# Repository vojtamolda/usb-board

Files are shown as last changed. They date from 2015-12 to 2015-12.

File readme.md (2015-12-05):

# USB Measuring Board & USB Attenuator

Wouldn't be cool to drive any experiment directly from your computer? Without the need to get up from your chair and touch things? Well, now your computer can directly flip switches, measure voltages, send signals and talk to other devices using the *USB Measuring Board* or *USB Attenuator*!

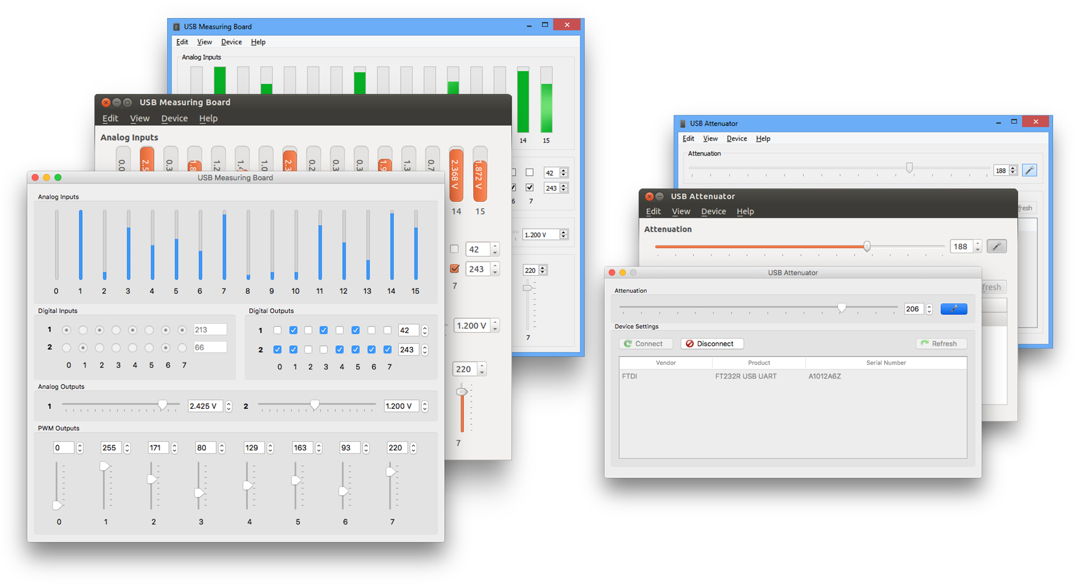
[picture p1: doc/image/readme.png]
board_diagram USB Measuring Board & USB Attenuator

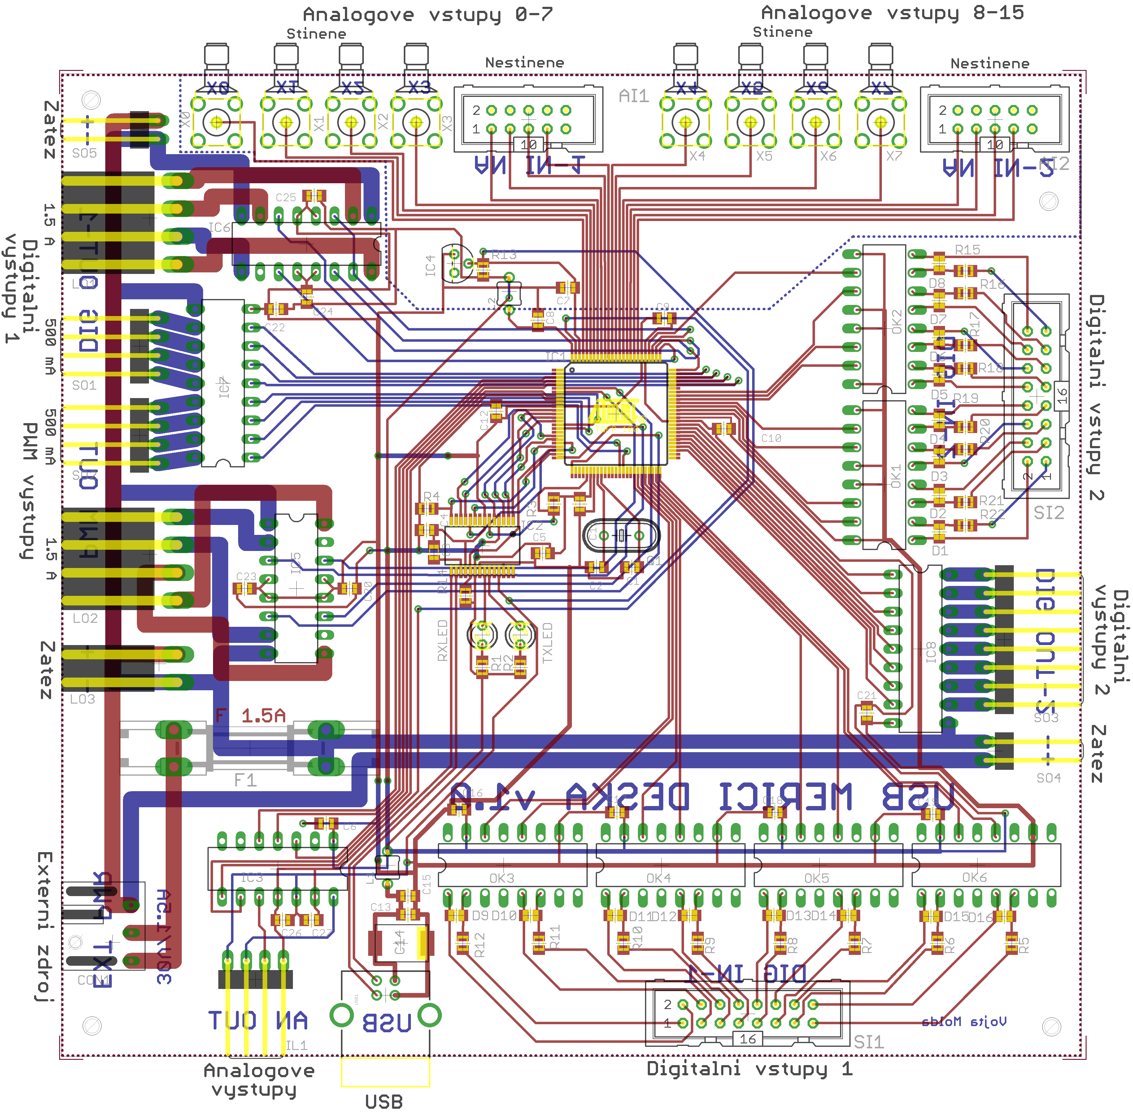
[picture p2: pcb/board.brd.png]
board_pcb Printed Circuit Board


If your applications is simple and requires just a few inputs and outputs then [*USB Attenuator*](/doc/attenuator.md) is the right solution. [*USB Measuring Board*](/doc/board.md) is more versatil and can handle control of more complex experiments. See [board.md](/doc/board.md) and [attenuator.md](/doc/attenuator.md) readme files for more details.

Both projects were originally inspired by the needs of the [Department of Low-Temperature Physics, Charles University, Prague](http://kfnt.mff.cuni.cz), but obviously range of application is much wider. *USB Measuring Board* was developed as part of my [bachelor thesis](/doc/thesis.pdf) written in 2009. If you're interested in how it all works, take a look at the  [prototypes](/prototypes/prototypes.md).

## Compilation
So... How do I build this monster? It's not as complicated as it looks. Build chain uses *QMake* (part of [*Qt framework*](http://qt.io)). Besides *Qt*, you'll need two libraries that provide USB communication - [*libftdi*](http://www.intra2net.com/en/developer/libftdi/index.php) and [*libusb*](http://libusb.info/). Tested platforms are Mac OS X 10.11, Ubuntu Linux 14.04 LTS and Windows 8, but chances are it would run on any platform supported by *Qt* and *libusb*.

Firmware powering the ATmega microprocessor requires it's own version C compiler, linker and standard C libraries called [*avr-toolchain*](http://savannah.nongnu.org/projects/avr-libc/). To upload the firmware no special programmer is needed. Microprocessor programming can be done over the USB cable by [*avrdude*](http://savannah.nongnu.org/projects/avrdude/).

#### Mac OS X
- Download and install latest version of *Qt* 5.x libraries from [here](http://www.qt.io/download/).
- Install *libftdi* library. [Homebrew](http://brew.sh/) installs *libusb* automatically as a dependency.
```bash
   # Get Homebrew OS X package manager here: http://brew.sh/.
   brew install libftdi
```
- Install [*avr-gcc*](https://gcc.gnu.org/wiki/avr-gcc), [*avr-libc*](http://savannah.nongnu.org/projects/avr-libc/)  and [*avrdude*](http://savannah.nongnu.org/projects/avrdude/) required to compile and upload firmware.
```bash
   # Alternatively download and install CrossPack.
   brew install avrdude
   brew tap larsimmisch/avr
   brew install avr-libc
```
- Compile both projects with *QMake* and make.
```bash
   # Alternatively open the .pro file in Qt Creator IDE.
   qmake board.pro
   qmake attenuator.pro
   cd firmware; make;
```
- Remove colliding OS X kernel extension and run the compiled application.
```bash
   # Remove AppleUSBFTDI kernel extension to prevent 'Unable to claim USB device' errors.
   sudo kextunload -bundle-id com.apple.driver.AppleUSBFTDI
```

#### Linux
- Install your distribution's default version of *Qt* 5.x libraries.
```bash
   # DEB-based distributions. (Ubuntu, Debian...)
   apt-get install qt5-default
   # RPM-based distributions. (RedHat, SUSE...)
   yum install qt5-default
```
- Install development version of *libftdi-dev* library. Package manager installs *libusb-dev* automatically as a dependency.
```bash
   # DEB-based distributions.
   apt-get install libftdi-dev
   # RPM-based distributions.
   yum install libftdi-dev
```
- Install [*avr-gcc*](https://gcc.gnu.org/wiki/avr-gcc), [*avr-libc*](http://savannah.nongnu.org/projects/avr-libc/)  and [*avrdude*](http://savannah.nongnu.org/projects/avrdude/) required to compile and upload firmware.
```bash
   # DEB-based distributions.
   apt-get install avrdude avr-gcc avr-libc
   # RPM-based distributions.
   yum install avrdude avr-gcc avr-libc
```
- Compile both projects with *QMake*.
```bash
   # Alternatively open the .pro file in Qt Creator IDE.
   qmake board.pro
   qmake attenuator.pro
   cd firmware; make
```
- Remove conflicting kernel module and run the compiled application.
```bash
   # Unload kernel module to prevent 'Unable to claim USB device' errors.
   sudo rmmod ftdi_sio
```

#### Windows
- Download and install latest version of *Qt* 5.x libraries from [here](http://www.qt.io/download/).
- Download and compile libraries required for USB communication.
  - Source code and documentation for *libusb* is available [here](http://github.com/libusb/libusb/)
  - Source code and documentation for *libftdi* is available [here](http://www.intra2net.com/en/developer/libftdi/repository.php).
  - Copy freshly compiled static libraries and headers (*ftdi.h*, *usb.h*, *libftdi.lib* and *libusb.lib*) into *lib/win32/*.
- Download and install [*WinAVR*](http://winavr.sourceforge.net/) required to compile and upload firmware.
- Compile both projects with *QMake*.
```bat
   :: Alternatively open the .pro file in Qt Creator IDE.
   qmake.exe board.pro
   qmake.exe attenuator.pro
   cd firmware; make.exe
```

## Schematics and PCB Layouts
Circuit schematics (.sch) and PCB layouts (.brd) files are designed with [Eagle CAD](http://www.cadsoftusa.com/). Free version for non-commercial use version can be downloaded [here](http://www.cadsoftusa.com/download-eagle/).

## License
This work is licensed under the [GNU GPL 3.0 License](http://www.gnu.org/licenses/gpl-3.0.html) © 2009.

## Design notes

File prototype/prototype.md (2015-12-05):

# Breadboard Prototypes

## What's this?
Following page contains descriptions of three simple prototype applications that served as proof of concept. These files are here to show and document the development path (i.e. dead ends) towards [USB Attenuator](/doc/attenuator.md) and [USB Measuring Board](/doc/board.md).

## Discover
This application tests basic functionality of the *libftdi* library. It detects and prints out a detailed list of all available FTDI chips. Any (FT232/245/2232 etc..) known model is detected and listed.

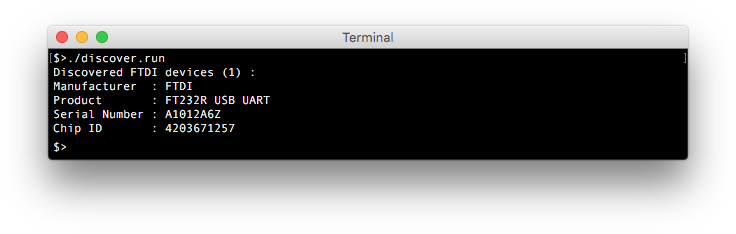
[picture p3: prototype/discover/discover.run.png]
bitbang_application Discover Prototype Application


If the application ends up with an error or doesn't detect any device, typically there's a collision between *libftdi* and OS kernel driver. Please, see the *Compilation* section of the [readme file](/readme.md) for more details on how to unload the colliding kernel driver for each OS.

## Bitbang
This prototype tests the bitbang mode. Bitbang mode allows direct access to pins of FT232R IC. Pins can be setup as either input or output. Based on the supplied argument, the application launches in two different modes -
input mode `i`, that reads state of connected switches or output mode `o`, which can for example blink LEDs.
 
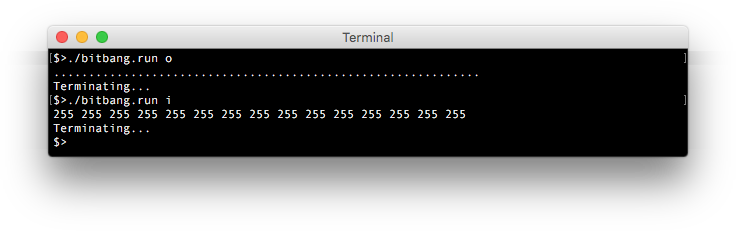
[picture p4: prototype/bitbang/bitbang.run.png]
bitbang_application Bitbang Prototype Application


Example connection schematics that can be used for input and output mode are shown on the following picture. In case of the output mode, every GPIO is connected to a 330Ω resistor and a LED. Input mode uses the same resistors as pull-downs and switches connect the GPIO lines to +5V.

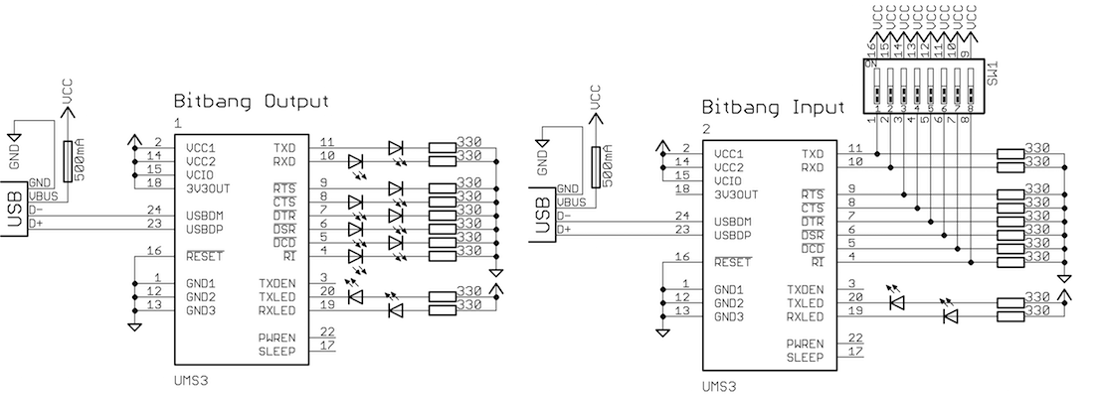
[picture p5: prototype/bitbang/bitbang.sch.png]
bitbang_schematics Bitbang Prototype Schematics


PS: I know 330 Ω pull-down resistors are a silly idea, since it wastes a ton of power when the switches are on, but I'm too lazy to change the breadboard and nobody cares about prototypes anyway :-)

## ATmega168
This breadboard prototype is a smaller brother of [USB Measuring Board](/doc/board.md). Instead of gigantic ATmega1280 with hundreds of legs, this prototype uses ATmega168 in DIP-28 package. Both microcontrollers use the same RISC instruction set, so the main difference is only the number of GPIO ports.

Key feature of the prototype is the ability to program the microcontroller directly via the USB cable, without the need for any external programmer. This allows for quick development cycles and easy firmware updates once the board is deployed into production.

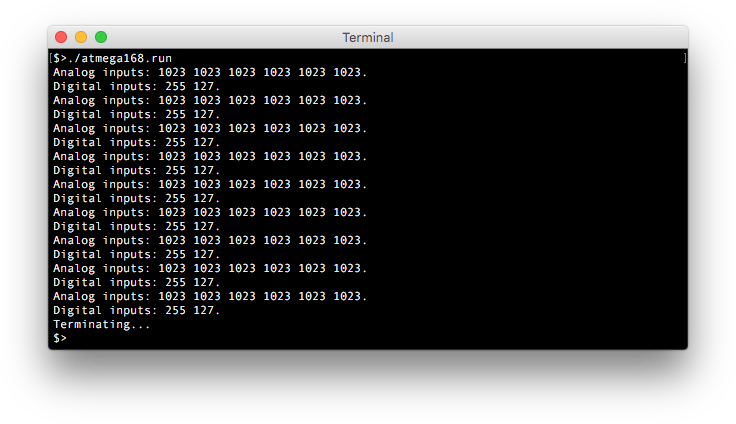
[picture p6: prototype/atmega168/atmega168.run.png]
atmega168_application ATmega168 Prototype Application


Application running on the PC and the firmware running on the ATmega microcontroller talk to each other via USB to serial port converter provided by the FT232R IC sitting on UMS3 module. UMS3 is just a convenient breakout DIP package for FT232R IC and it isn't used in the production models. After receiving data packet from the serial port ATmega168 firmware sets the values of analog outputs via SPI interface and sets the state of the digital output GPIO pins. After that it sends back the values of analog and digital inputs.

Controlling application running on the PC periodically scans and prints out the values of analog (10-bit value) and digital inputs to the terminal. Values of analog and digital outputs transmitted into the microcontroller are hard-coded into the source code.

Following picture shows schematics of the ATmega breadboard and list of used ICs and their function:

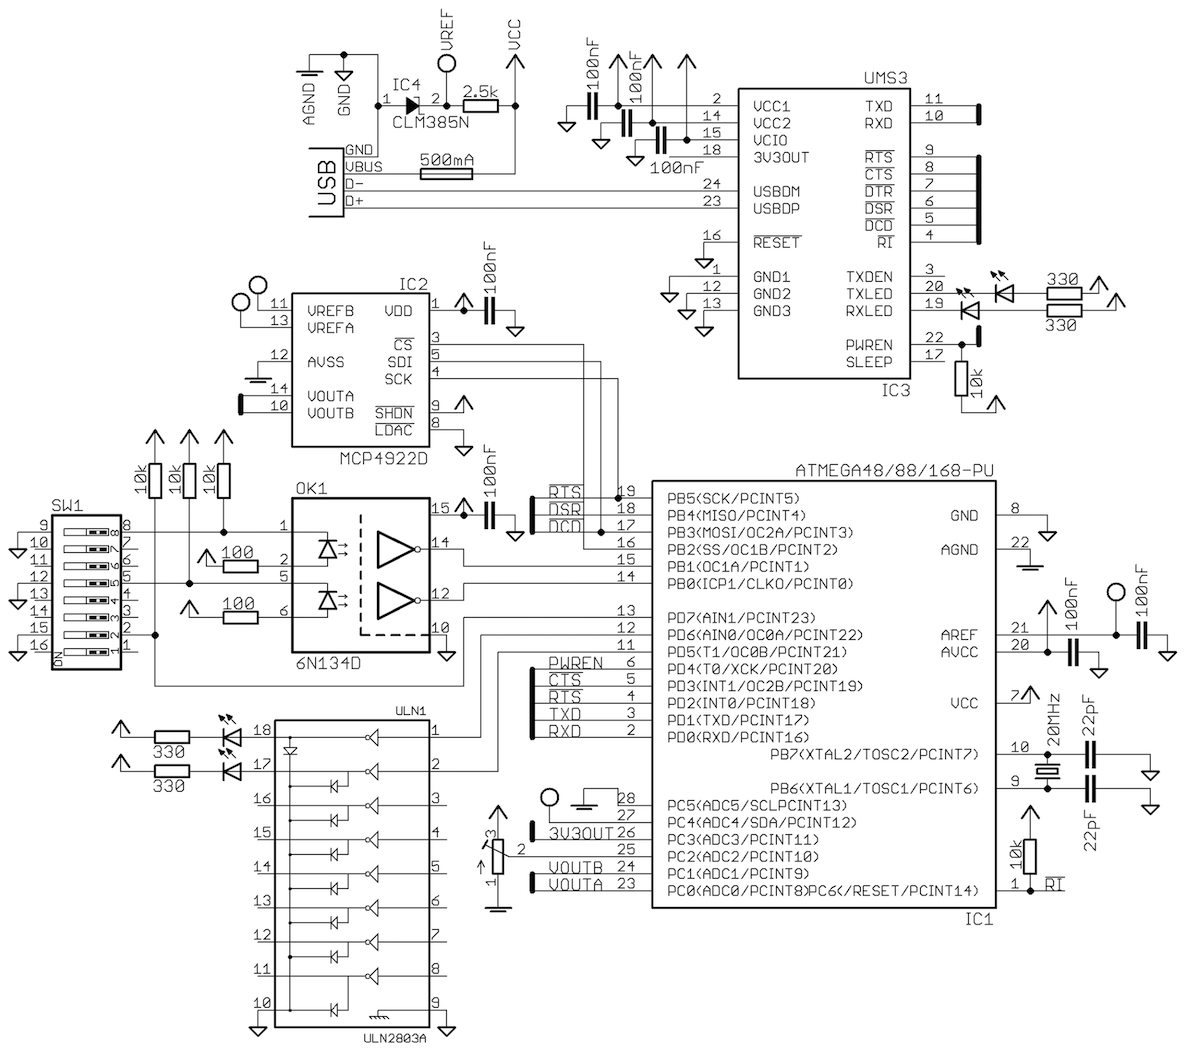
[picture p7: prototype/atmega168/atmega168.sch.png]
atmega168_schematics ATmega168 Prototype Schematics


| IC | Interface | Function
|---|---|---
| ATmega168 | UART | RISC 8-bit microcontroller (running at 20 MHz)
| UMS3 | USB | USB to UART converter (breakout for FT232R)
| MCP4922P  | SPI | Digital to analog converter (12-bit precision)
| ULN2803A  | GPIO | Darlington driver for digital outputs (500mA max. current)
| 6N134D | GPIO | Optocoupler for galvanic separation of digital inputs
| CLM385M | N/A | Voltage 2.5V reference for digital-analog and analog-digital converters

Here's a photograph of the assembled breadboard in it's full beauty :) 

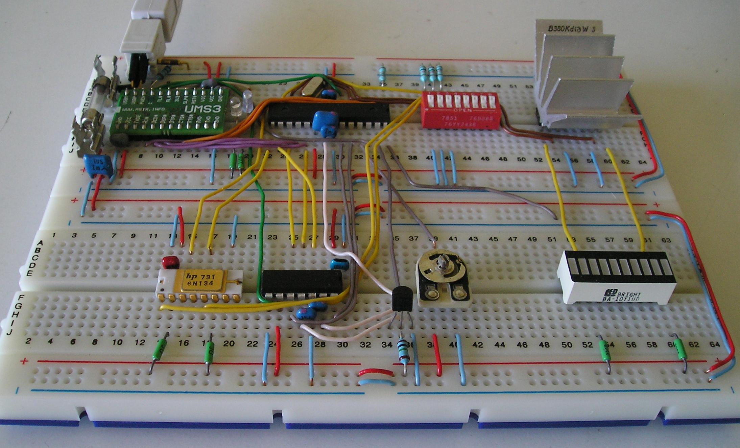
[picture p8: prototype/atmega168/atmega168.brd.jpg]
atmega168_breadboard ATmega168 Prototype Breadboard


For more details, please see *Chapter 5 - Prototype* of the bachelor [thesis](/doc/thesis.pdf) (available only in Czech).

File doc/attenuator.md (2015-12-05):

# USB Attenuator

## How does it work?
Essentially, you stick USB cable into the gadget one side and custom parallel port signals get out on the other side. To make the device work two things are needed - some hardware and an application that can talk to that hardware.

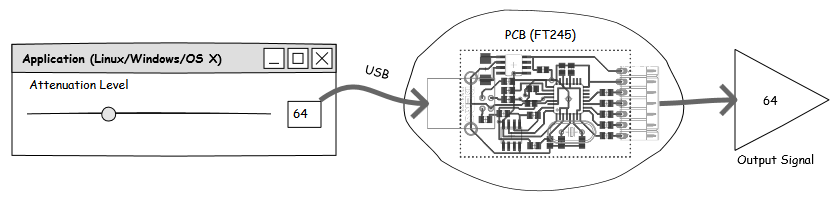
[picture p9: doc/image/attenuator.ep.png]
diagram Diagram


## Application
Under the hood of the *USB Attenuator* application sits the [*Qt* framework](http://qt.io). Hardware communication uses [*libftdi*](http://www.intra2net.com/en/developer/libftdi/index.php) and [*libusb*](http://libusb.info/). These libraries allow the USB communication code to be written only once, since they provide an abstraction layer from the underlying OS specific API.

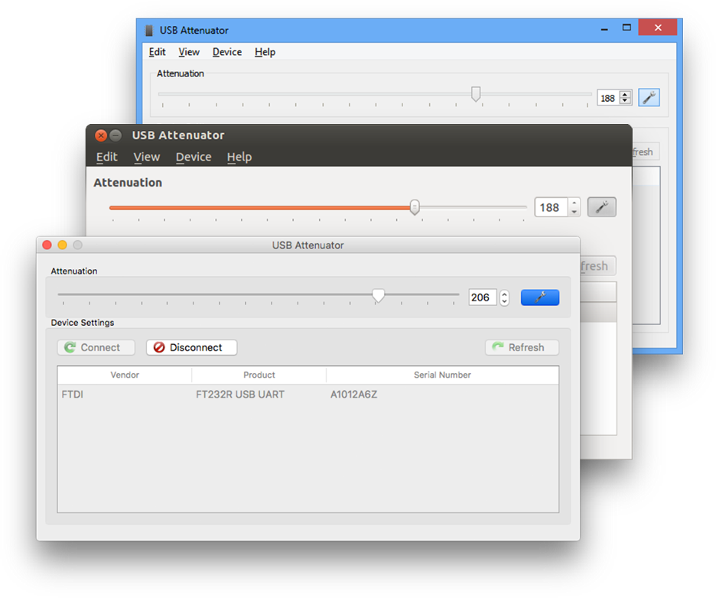
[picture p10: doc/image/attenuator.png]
application Application


For detailed instructions on how to compile the application, please see the [readme.md](readme.md) file. No worries. It's not as complicated as it sounds.

## Electronics
All the magic happens thanks to the built-in bit-bang mode of the FT245 IC. Other parts are there just to help the FT245 do it's job. You can can read tons more details about the IC in the [datasheet](http://www.ftdichip.com/Support/Documents/DataSheets/ICs/DS_FT245R.pdf).

### Schematics
The PCB contains FT245 (*IC1*) chip which is essentially a black-box with USB (2.0 480Mb/s) on one side and parallel port (RS-485) on the other side. The rest of the parts is there just to make the FT245 work. The FT245 chip is a bit sclerotic and tends to forget its name (Vendor and Product IDs). Because of this there's a three-wire serial EEPROM (93C46 - *IC3*) that keeps the configuration data. Old fashioned RS-485 use +/- 5 V levels so the board is equipped with a voltage converter (ICL7660 - *IC2*). The rest is just standard connectors, filtering capacitors, ferrite cores and resistors.

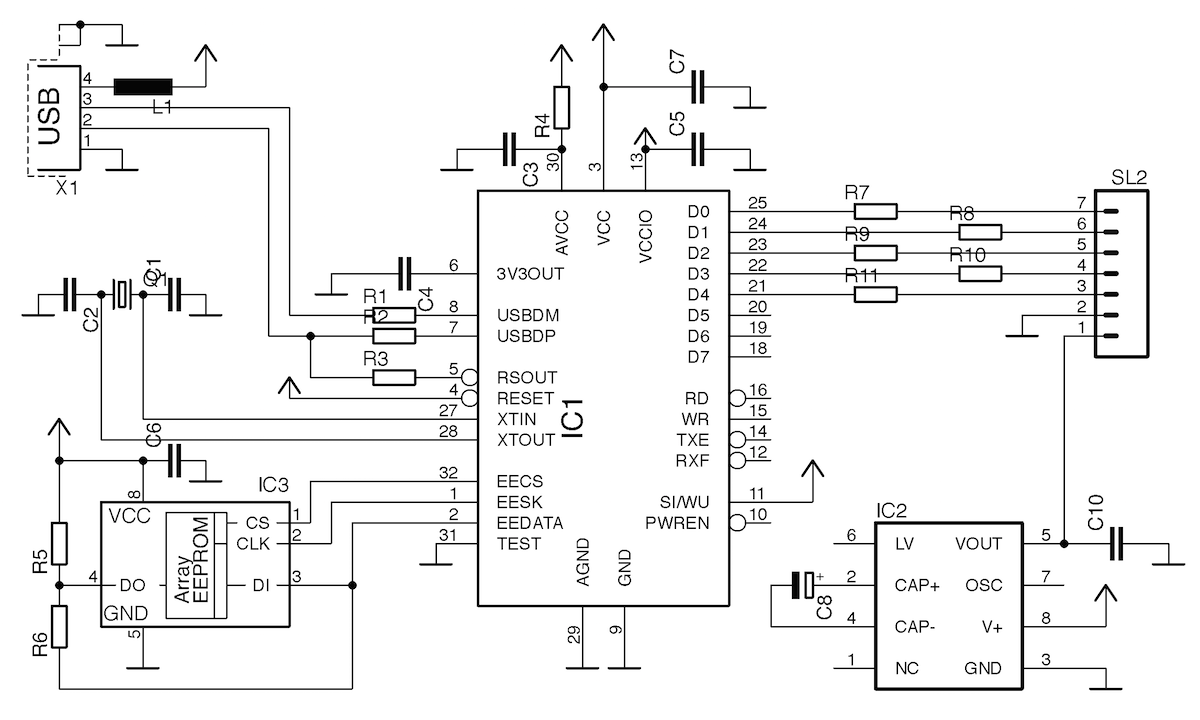
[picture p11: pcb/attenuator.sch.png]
schematics Schematics


### Printed Circuit Board
The PCB is designed as two-sided, but it's possible to use only one sided etching photomask and three jumper wires, which is a good compromise that prevents alignment problems that arise with two sided PCBs. Happy soldering!

| IC | Interface | Function
|---|---|---
| FT245BL (IC1) | USB | USB to parallel port converter
| ICL7660SA (IC2) | N/A | Negative voltage converter (outputs -5V)
| 93-C46ASN (IC3) | SPI | Microwire compatible serial 1kB EEPROM (keeps USB descriptors)

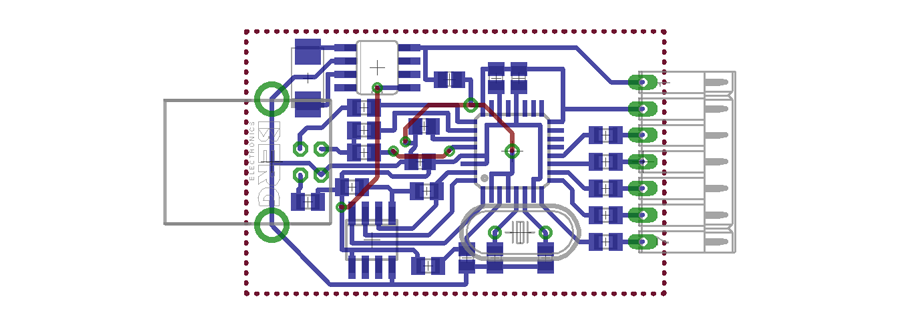
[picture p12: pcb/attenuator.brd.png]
pcb Printed Circuit Board


 - Dimensions 25 x 40 x 12 mm / 1.0 x 1.6 x 0.5 in
 - Operating temperature range: -40 to +70 °C / -40 to +160 °F
 - Weight: 3.8 g / 0.16 oz

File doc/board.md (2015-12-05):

# USB Measuring Board

## How does it work?
Essentially, you stick USB cable into the gadget one side and whole bunch of input and output signals start to blink on the other side. To make the device work two things are needed - some hardware and an application that can talk to that hardware.

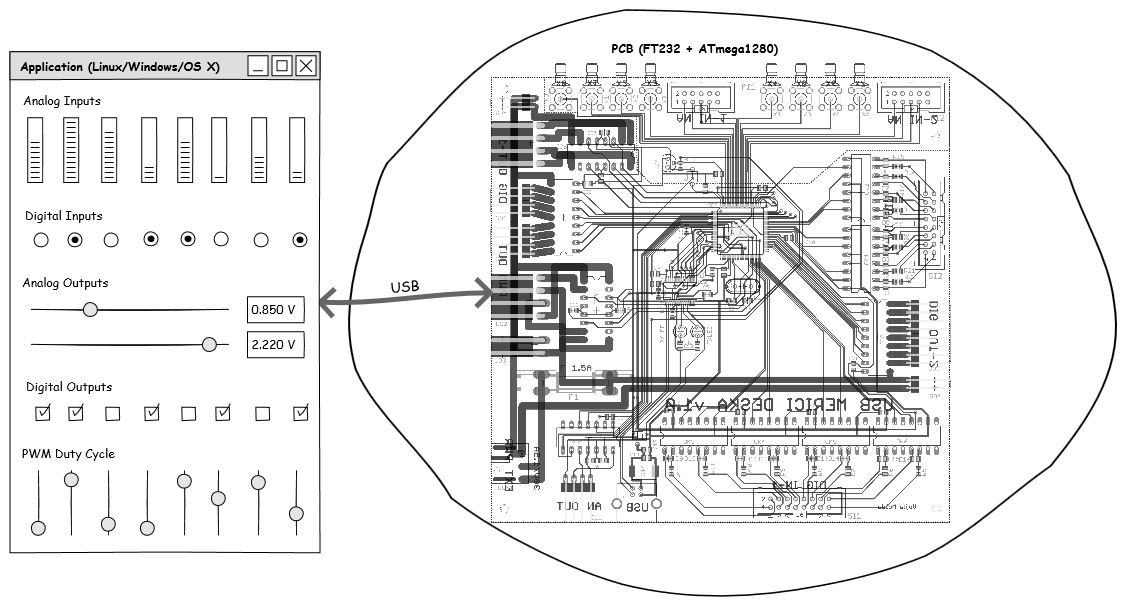
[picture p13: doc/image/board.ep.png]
diagram Diagram


## Application
Under the hood of the *USB Measuring Board* application sits the [*Qt* framework](http://qt.io). Hardware communication uses [*libftdi*](http://www.intra2net.com/en/developer/libftdi/index.php) and [*libusb*](http://libusb.info/). These libraries allow the USB communication code to be written only once, since they provide an abstraction layer from the underlying OS specific API.

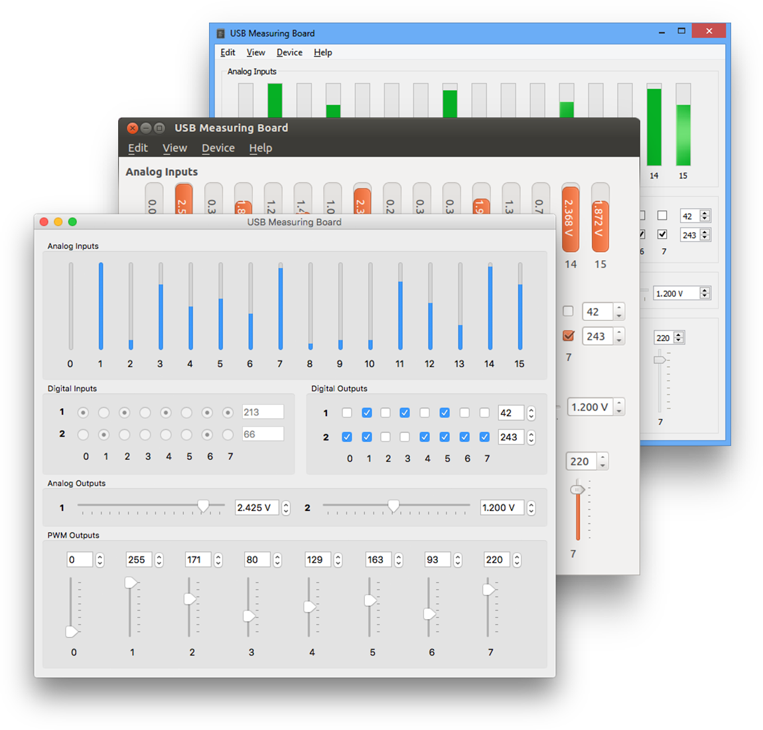
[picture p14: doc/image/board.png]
application Application


For detailed instructions on how to compile the application, please see the [readme.md](readme.md) file. No worries. It's not as complicated as it sounds.

## Firmware
Key feature of the board design is the ability to program the microcontroller directly via the USB cable, without the need for any external programmer. This allows quick development cycles and easy firmware updates once the board is deployed into production. 

Controlling application running on the PC periodically polls the board. The packet going into the device contains fresh values of digital and analog outputs the user has set. Board sends back measured values of digital and analog inputs which are then displayed to the user. 

After receiving a data packet from the serial port firmware running on the ATmega1280 sets the desired value of all outputs and PWMs. Then it sends back the values of analog and digital inputs.

## Electronics
All the magic happens thanks to just two ICs - ATmega 1280 and FT232 IC. ATmega 1280 microcontroller is the brain of the operation and FT232 provides USB communication. Other parts are there just to help these two do their job. You can read tons more details about both ICs in their datasheets [here](http://www.atmel.com/Images/Atmel-2549-8-bit-AVR-Microcontroller-ATmega640-1280-1281-2560-2561_datasheet.pdf) and [here](http://www.ftdichip.com/Support/Documents/DataSheets/ICs/DS_FT245R.pdf).

#### Schematics
Following picture shows schematics of the ATmega breadboard and list of used ICs and their function:

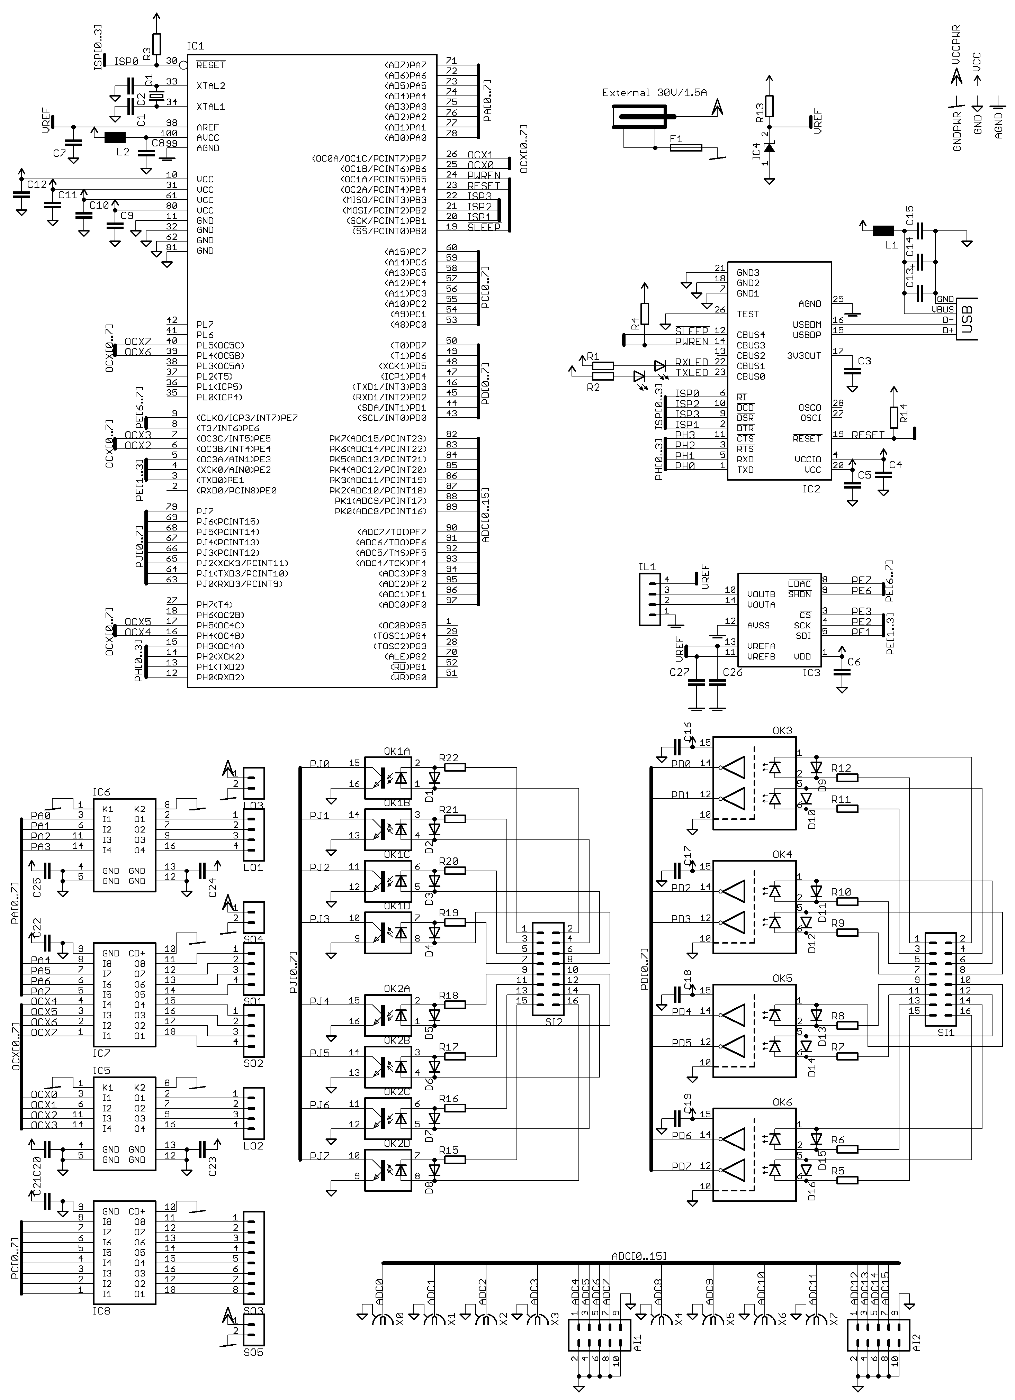
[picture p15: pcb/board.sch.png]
schematics Schematics


The PCB contains FT232 (*IC2*) chip which works as a black-box with USB (2.0 480Mb/s) on one side and serial port (RS-232) on the other side. The logic of the communication is handled in the ATmega1280 (*IC1*) microcontroller. The rest of the parts is there just to support the microcontroller to do its job.

Outputs of ATmega1280 can be loaded only with 20mA current. Because of this limitations all outputs are provided with power amplification. Darlington driver ULN2803A (*IC6,8*) can handle 500mA and ULN2064B outputs are capable of 1.5A. Two analog outputs are provided by MCP4922P (*IC3*) 12-bit analog converter. The MCP4922P and the ATmega microprocessor communicate via SPI bus.

Digital inputs are galvanically separated from the board to reduce the risk of damage. Two kinds of optocouplers are used - PC849 (*OK1-2*) and HCPL2630 (*OK3-6*).

#### Printed Circuit Board
The PCB is designed as two-sided and tolerances are relatively large, so it can be manufactured via traditional laboratory optical etching mask.

| IC | Interface | Function
|---|---|---
| ATmega1280 (IC1) | UART | RISC 8-bit microcontroller (running at 16 MHz)
| FT232R (IC2) | USB | USB to UART converter
| MCP4922P (IC3) | SPI | Digital to analog converter (12-bit precision)
| CLM385M (IC4) | N/A | Voltage 2.5V reference for digital-analog and analog-digital converters
| ULN2803A (IC6,8) | GPIO | Darlington driver for digital outputs (500mA max. current)
| ULN2064B (IC5,7) | GPIO | Darlington driver for digital outputs (1.5A max. current)
| PC849 (OK1-2) | GPIO | Optocoupler for galvanic separation of digital inputs (4 channel)
| HCPL2630 (OK3-6) | GPIO | Optocoupler for galvanic separation of digital inputs (2 channel)

pcb Printed Circuit Board

 - Dimensions 140 x 135 x 20 mm / 5.5 x 5.3 x 0.8 in
 - Operating temperature range: -40 to +70 °C / -40 to +160 °F
 - Weight: 130 g / 4.5 oz

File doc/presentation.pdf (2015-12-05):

# Univerzální USB modul pro sběr dat a řízení fyzikálního experimentu

## Vojta Molda

# Obsah

# - Zadání

# - Zvolená koncepce - Funkce zařízení - Realizace - Software

# - Připomínky a poděkování

# Cíle práce

# Cíle práce

- Navrhněte modul, který bude připojen přes USB rozhraní k libovolnému PC a jehož vstupy a výstupy bude možné modifikovat pro připojení k libovolnému fyzikálnímu experimentu.
- Napište obslužný program v C++ k tomuto modulu pro operační systém Windows XP.
- Vzhledem k univerzálnosti modulu je třeba počítat s minimálně 16 analogovými a digitálními vstupy.
- Výstupy modulu budou rovněž analogové i digitální. Digitální výstupy budou minimálně velikosti 8b. Nejméně část z nich bude schopna výkonového zatížení.

# Zvolená koncepce

# Zvolená koncepce

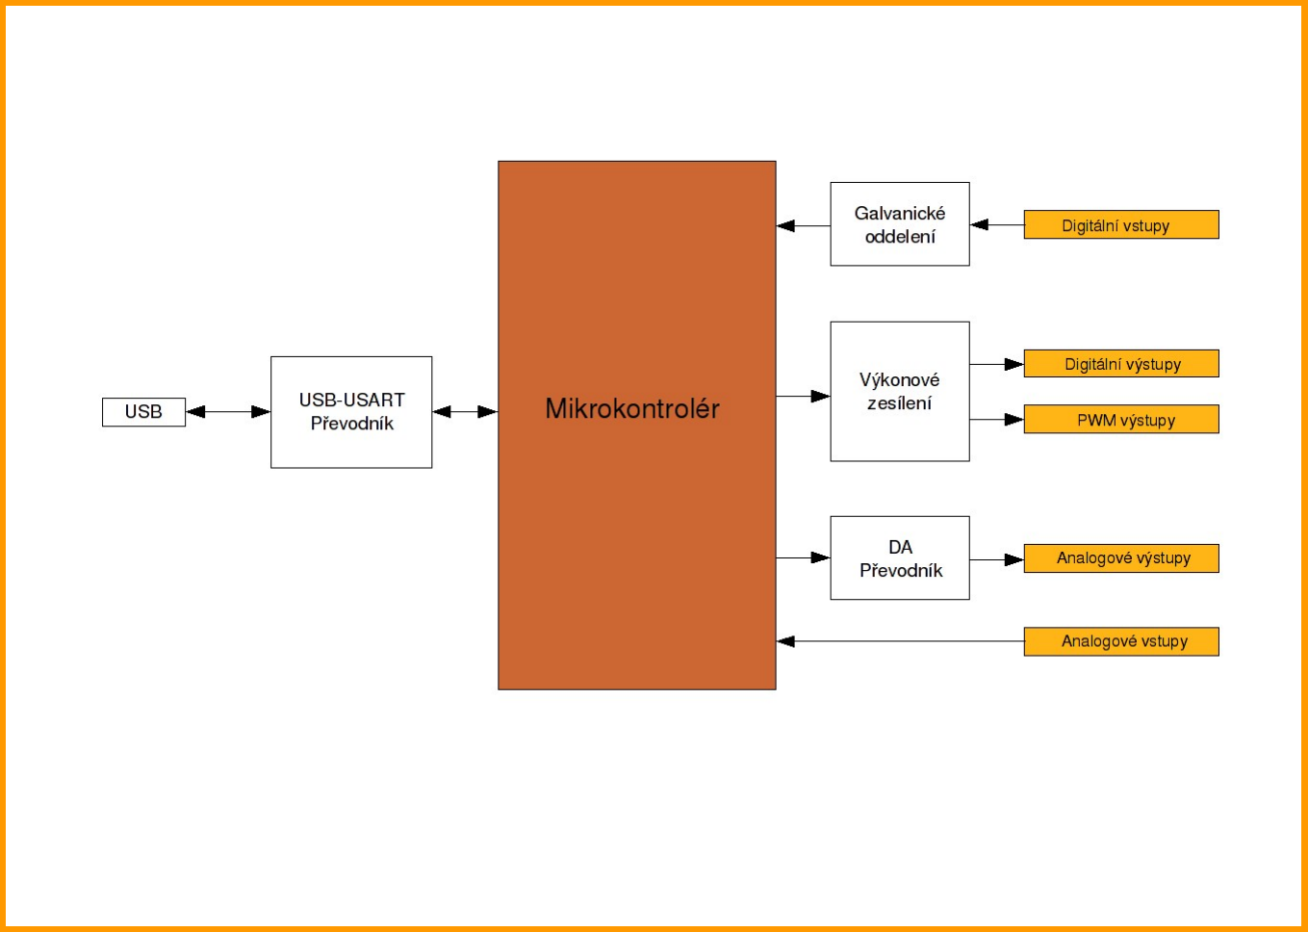
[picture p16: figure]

# Funkce zařízení

# Funkce zařízení

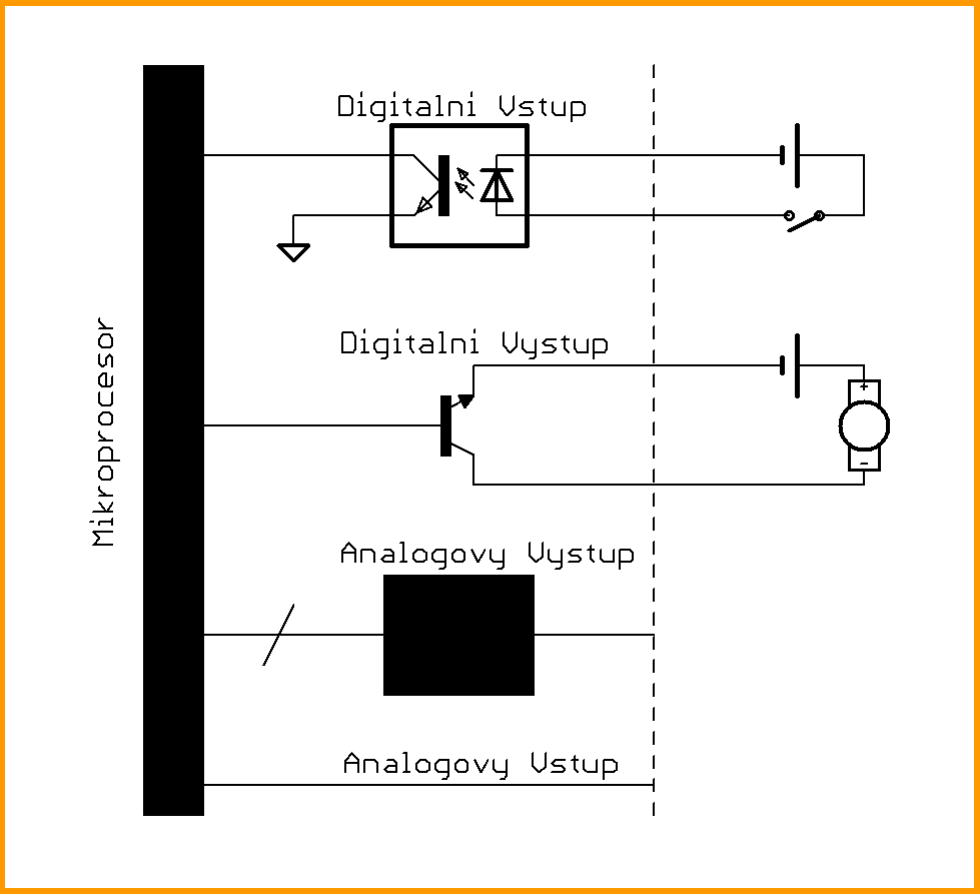
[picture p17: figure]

# Realizace

# Realizace

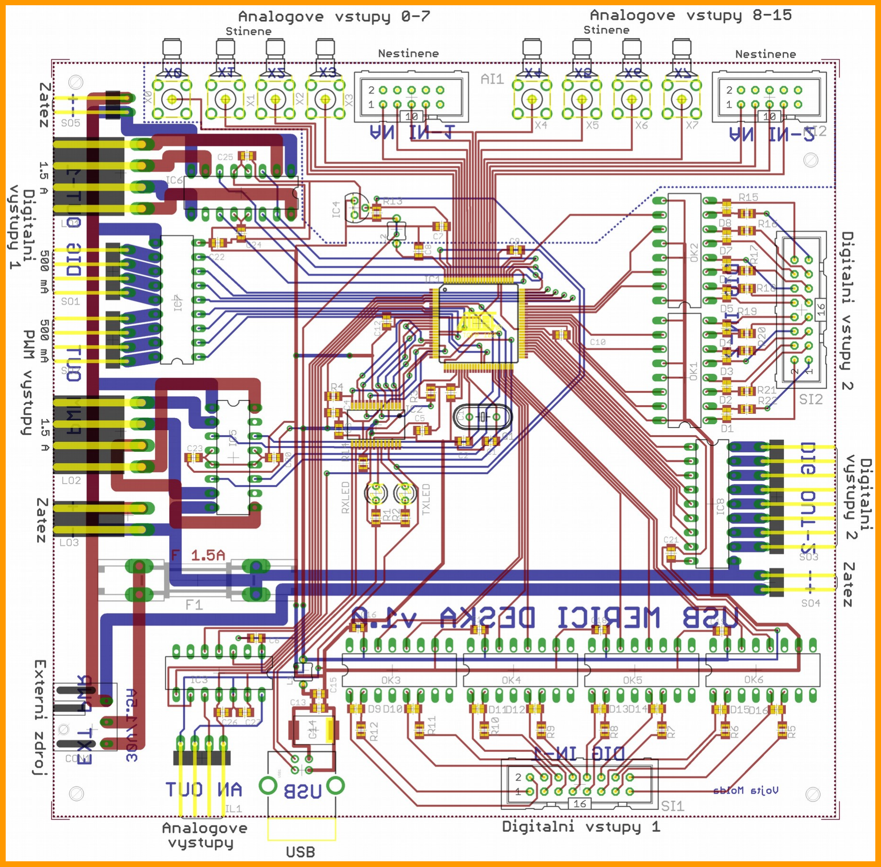
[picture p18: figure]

# Software

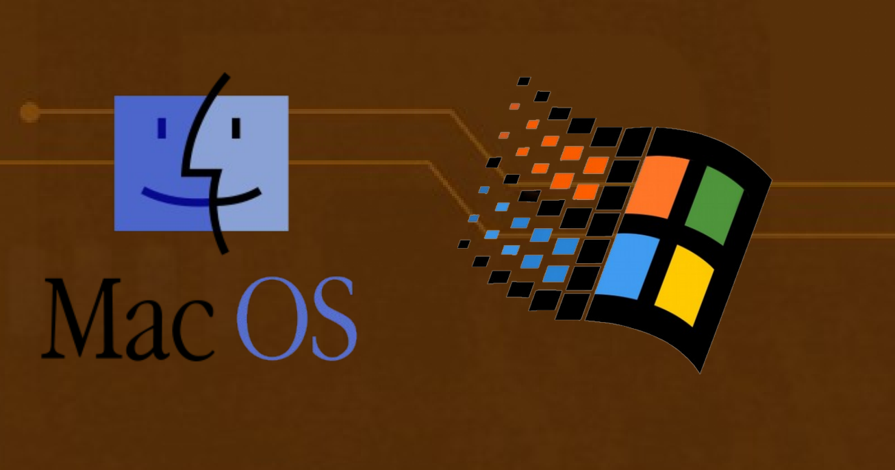
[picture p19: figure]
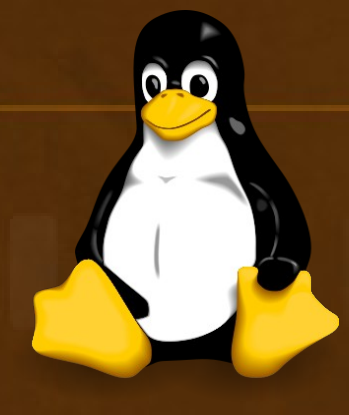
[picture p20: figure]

# Software

- Multiplatformnost – Linux, Windows, Mac OS, Solaris*, FreeBSD*, OpenBSD*, ...

## - Jednoduchá modifikovatelnost firmware mikroprocesoru

## - Otevřenost zdrojových kódů

* - Nebylo testováno

# Poděkování a připomínky

# Poděkování a připomínky

# Připomínky oponenta

# Poděkování

## - D/A Převodník - Statické a dynamické vlastnosti modulu

- Ing. Miloš Pfeffer, Csc.

## - KFNT MFF UK - Elektronické praktikum

# Některé vlastnosti modulu

# Reakční doba A/D převodníku

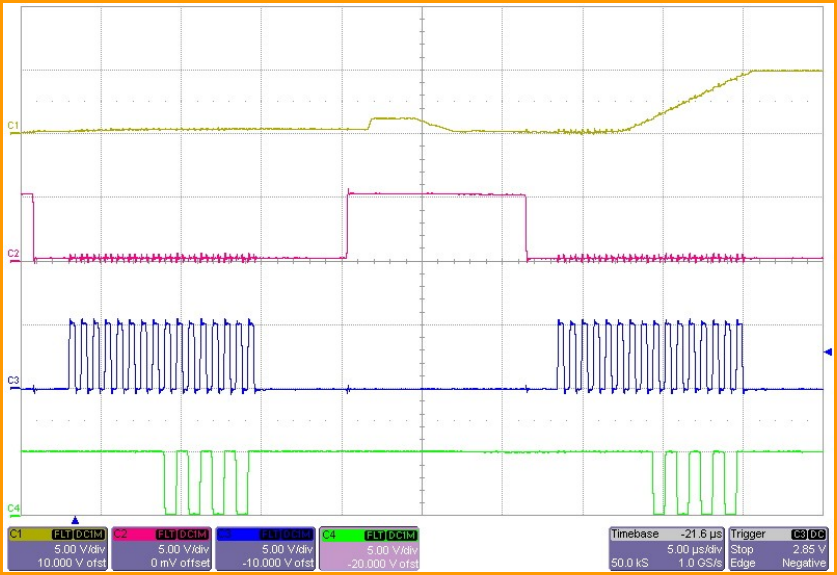
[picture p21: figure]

# Spínací proud digitálních vstupů

# Změřené hodnoty

# Hodnoty z manuálu

## - PC849 ~ 2.6 mA - 6N134 ~ 0.2 mA

## - PC849 – 2.54 mA - 6N134 – 0.21 mA

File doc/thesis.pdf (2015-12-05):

Univerzita Karlova v Praze Matematicko-fyzikální fakulta

BAKALÁ RSK ˇ | A PR ´ | ACE ´

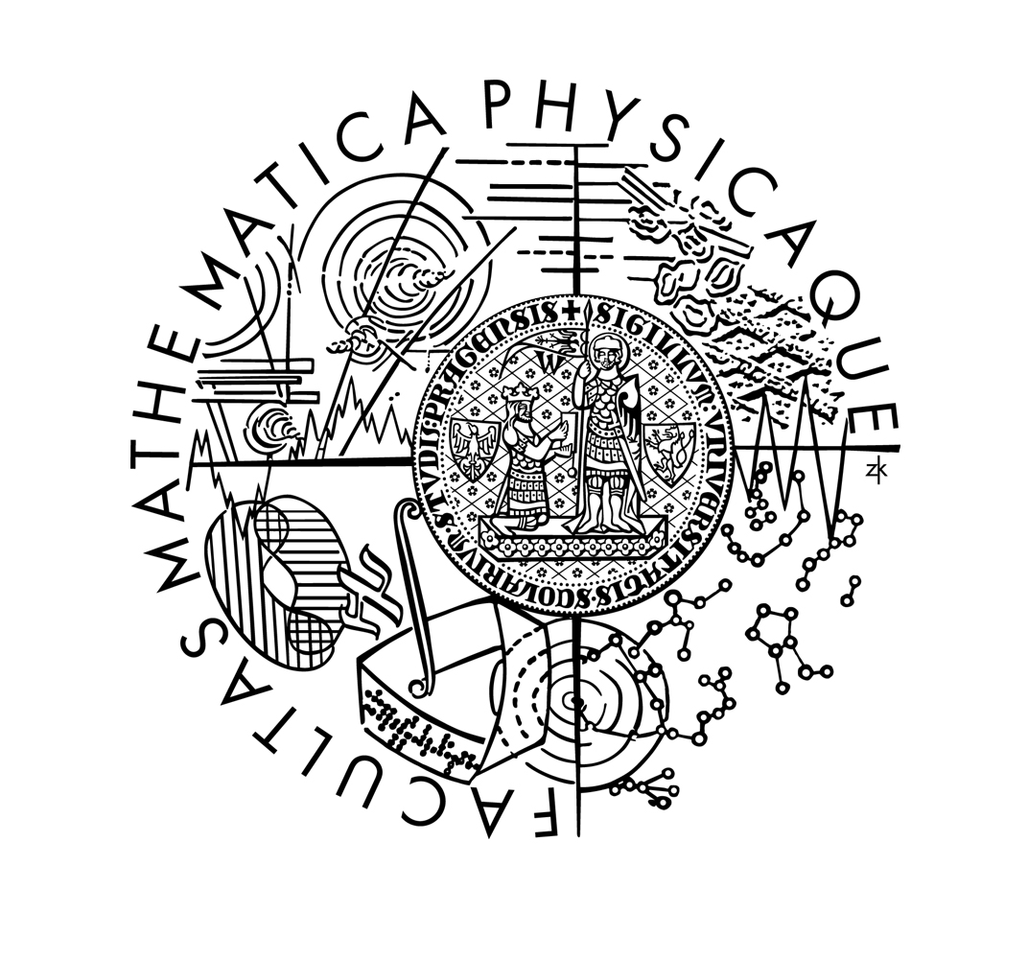
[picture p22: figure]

## Vojta Molda

## Univerzální USB modul pro sběr dat a řízení fyzikálního experimentu

Katedra fyziky nízkých teplot

Vedoucí bakalářské práce: Ing. Miloš Pfeffer, CSc.

Studijní program: Obecná fyzika

2009

1

Chtěl bych v prvé řadě poděkovat vedoucímu mé práce Ing. Miloši Pfefferovi, CSc., za neocenitelné rady, konzultace, připomínky a pomoc při výrobě i návrhu plošných spojů. Bez této pomoci by práce vznikala s daleko větší námahou a s mnohem menší radostí.
Velké díky také patří Katedře fyziky nízkých teplot MFF UK, která nesla veškeré náklady na součástky spojené se stavbou a vývojem měřící desky.
V neposlední řadě chci poděkovat volitelnému předmětu Elektronické praktikum, jehož úloha s USB modulem byla zdrojem inspirace a poskytla základní myšlenku, která se rozšířila až do zde prezentované podoby. Je prakticky jisté, že bez tohoto předmětu by tato práce nemohla vzniknout.

Prohlašuji, že jsem svou bakalářskou práci napsal samostatně a výhradně s použitím citovaných pramenů. Souhlasím se zapůjčováním práce a jejím zveřejňováním.

V Praze 29. května 2009 | Vojta Molda

2 | 0 Introduction

# 0 Introduction

Title: Universal USB Module for Data Aquisition and Control of Physical Experiments Author: Vojta Molda
Author’s email: vojta.molda@gmail.com
Department: Department of Low-Temperature Physics
Supervisor: Ing. Miloš Pfeffer, CSc.
Supervisor’s email: Milos.Pfeffer@mff.cuni.cz

## 0.1 Abstract

Work concentrates on design and construction of measuring device, which communicates over USB bus. Designed measuring device contains 16 analog inputs with 10-bit resolution, 16 TTL level digital inputs protected by optocoupler, 16 digital open-collector outputs out of which is 4 capable of whitstandig current up to 1.5 A, 8 PWM outputs also capable of handling current up to 1.5 A and 2 analog outputs with 12-bits resolution. Key point in the design is ability to program controlling microprocessor directly in the application without necessity to connect any external programmer. That allows large variety and ease of usage. Tools required for programming together with source codes in C language are included on CD. Emphasis was put on free technologies nad portability.

Keywords: USB, measuring, microprocessor, data acquisition

3

# 1 Uvod

´

Název práce: Univerzální USB modul pro sběr dat a řízení fyzikálního experimentu Autor: Vojta Molda
Email autora: vojta.molda@gmail.com
Katedra (ústav): Katedra fyziky nízkých teplot
Vedoucí bakalářské práce: Ing. Miloš Pfeffer, CSc. Email vedoucího: Milos.Pfeffer@mff.cuni.cz

## 1.1 Abstrakt

Práce se zabývá procesem vývoje, návrhu a stavby měřícího a řídícího zařízení, které komunikuje po sběrnici USB. V práci navržená a postavená měřící deska obsahuje 16 analogových vstupů s 10-bitovým rozlišením, 16 digitálních vstupů TTL úrovně chráněných optovazbou, 16 digitálních výstupů typu open-kolektor, z nichž 4 jsou zatižitelné proudem do 1.5 A, 8 PWM výstupů s proudovou zatížitelností taktéž do 1.5 A a 2 analogové výstupy s rozlišením 12-bitů. Stěžejním bodem návrhu je programovatelnost řídícího mikroprocesoru přímo v aplikaci bez nutnosti připojovat externí programátor. Z toho plyne široká univerzálnost a snadné použití měřící desky. Potřebné nástroje spolu se zdrojovými kódy v jazyce C jsou k dispozici na přiloženém CD. Důraz byl kladen na svobodné technologie a co největší multiplatformnost.

Klíčová slova: USB, měření, mikroprocesor, sběr dat

4 | 1 Uvod ´

## 1.2 Zadání a motivace práce

| • Navrhněte a realizujte autonomní univerzální externí modul s vlastním napájením a požadovanými analogovými i digitálními vstupy a výstupy, který bude připojen přes USB rozhraní k libovolnému PC a jehož vstupy a výstupy bude možné modifikovat pro

připojení k libovolnému fyzikálnímu experimentu.

| • Napište obslužný program v C++ k tomuto modulu pro operační systém Windows XP.
| • Vzhledem k univerzálnosti modulu je třeba počítat s minimálně 16 analogovými a
digitálními vstupy.
| • Výstupy modulu budou rovněž analogové i digitální. Digitální výstupy budou minimálně velikosti 8 b. Nejméně část z nich bude schopna výkonového zatížení (např. pro řízení

krokových motorů).

| Současná generace PC již upouští od zaběhlých počítačových I/O portů (RS-232, Cen-
tronix, aj.), používaných často pro sběr dat a on-line řízení fyzikálních experimentů. Jejich roli převzalo definitivně rozhraní USB, které je vzhledem k rychlosti přenosu i v možnosti řetězení optimální volbou i pro připojení přístrojů fyzikálního experimentu. Právě pro tyto účely je třeba mít univerzální modul, který by zprostředkoval komunikaci mezi USB rozhraním počítače a nejrůznějšími vstupy a výstupy připojitelných zařízení. Takovýto modul se běžně na trhu však nevyskytuje, pokud ano, jeho možnosti v univerzálnosti jsou velmi omezené. Realizace takového modulu spolu s obslužným software v předkládané podobě by umožnila na experimentálních fyzikálních pracovištích rozšíření možností on-line komunikace PC s přístroji fyzikálního experimentu.

Obsah | 5

# Obsah

0 Introduction | 2
1 Uvod ´ | 3
2 Sběrnice USB | 7
3 Zvolená koncepce | 10
4 Použité integrované obvody | 13
4.6 PC849 - Ctyřnásobná analogová optovazba | | 17 ˇ
4.9 ULN2064B - Ctyřkanálové darlingtonové pole | | 18 ˇ
5 Prototyp | 20
6 USB měřící deska | 24

6 | Obsah
7 Software | 32
7.2 Rídící aplikace pro PC | | 33 ˇ
Literatura | 35

7

# 2 Sběrnice USB

## 2.1 Funkce

Rozhraní USB je uživatelsky přívětivé. Po připojení zařízení do USB portu vše další obslouží sám operační systém (instalaci a zavedení ovladačů). Práci spojenou s instalací a zaváděním ovladačů zařídí operační systém sám, aniž by tím byl uživatel obtěžován.
Tato jednoduchost z uživatelského hlediska je vyvážena složitější prací pro vývojáře zařízení. Každé zařízení musí obsahovat minimálně řadič schopný pracovat s USB sběrnicí. Ten navíc není nijak jednoduchý ani úplně levný. Pracuje s přenosovými frekvencemi v řádech desítek MHz a je vybaven značně rozsáhlým firmwarem. Po softwarové stránce je nutný ovladač, jehož psaní také není nejsnadnější. Navíc pokud chceme uvést na trh nové zařízení, je nutné požádat organizaci USB o přidělení unikátního čísla dodavatele VID (vendor ID). To se děje za poplatek zhruba $ 2 000.
Cílem standardu bylo nahradit velké množství různých konektorů na zadní straně počítačů, zjednodušit způsob softwarové komunikace periferií a odstranit konektory s piny.
Rozhraní USB je tvořeno čtyřmi vodiči. Jejich názvy jsou GND, VCC, D+, D-. Signály na D+, D- slouží k diferencíálnímu přenosu dat. Používané napět’ové úrovně jsou 0 V a 3.3 V. Na VCC se přivádí napětí 5 V. To umožňuje napájení menších zařízení přímo ze sběrnice bez nutnosti externích kabelů. Standartně lze odebírat proud 100 mA. Po domluvě s rozbočovačem až 500 mA. GND vodič rozvádí po sběrnici zem.
USB zařízení musí být schopna při absenci komunikace na sběrnici snížit svou spotřebu. Absencí komunikace na sběrnici se indikuje USB suspend režim pro připojená zařízení. Hlavním cílem je zvýšit výdrž baterií laptopů. Povolený proudový odběr v USB suspend režimu je 500 µA, pokud zařízení nemá schpnost remote wakeup¹ nebo na 2.5 mA, pokud má schopnost remote wakeup [12, str. 32].
Hvězdicovitá topologie umožňuje místo zařízení připojit do portu rozbočovač (hub). Každý rozbočovač má na svém výstupu USB porty, do kterých lze připojovat další zařízení, respektive huby. Maximální počet hubů zapojených v sérii je 5. Toto omezení je dáno přírozeně vznikajícím zpožděním v každém hubu. Nejvyšší možný počet zároveň připojených zařízení včetně hubů je 127. Verze sběrnice USB 1.1 je povolená délka propojovacího kabelu 3 m, u USB verze 2.0 je to již 5m. [12, str. 447].
První generace USB standardu označovaná jako USB 1.1 umožňuje zařízením přenos na dvou rychlostech low speed (1.5 Mbit/s) a full speed (12 Mbit/s) i nižší z obou rychlostí mnohonásobně překračuje možnosti sériového portu. Volba rychlosti přenosu probíhá 1.5 kΩ pull-up rezistorem na linku D+ pro full speed respektive D- pro low speed zařízení. Schéma

1Remote wakeup je schopnost probrat master zařízení z USB suspend režimu. Typické použití je probuzení notebooku z úsporného režimu při zmáčknutí klávesy nebo kliknutí myši.

8 | 2 Sběrnice USB

zapojení je na obrázku 2.1.

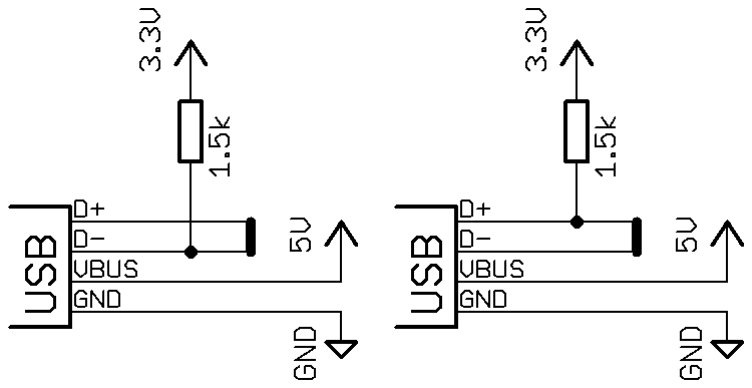
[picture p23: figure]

Obrázek 2.1: Zapojení pull-up rezistoru pro výběr rychlosti. Vlevo low a vpravo full speed zařízení.

Ukázalo se, že přenosové rychlosti první generace USB nedosahují dostatečných velikostí pro nově vyvinutá zařízení jako například externí pevné disky, flash paměti, digitální fotoaparáty nebo kamery. Proto byla na konci roku 2001 standardizována specifikace USB 2.0. Teoretická propustnost se zvýšila téměř čtyřicetinásobně na 480 Mbit/s (high speed). Zároveň zůstala zachována zpětná kompatibilita se starším hardware. Volba rychlosti USB 2.0 zařízení probíhá softwarově. Zařízení se tváří jako full speed s pull up rezistorem na D+ a komunikací s operačním systémem si vyjedná vyšší přenosovou rychlost.

## 2.2 Přenos dat

Na sběrnici USB může být pouze jedno zařízení typu master. Tím je obvykle stolní PC, latptop nebo některý typ PDA. Veškerá aktivita na sběrnici vychází od master zařízení. Zádné ˇ jiné zařízení nemůže vysílat data samo od sebe. Data se po sběrnici posílají v rámcích (frame) o délce přesně 1 ms. V rámci jednoho framu běžně posílá své pakety několik zařízení, přičemž se mohou vyskytovat pakety s low i full speed přenosovými rychlostmi. High speed přenos se uskutečňuje v mikrorámcích o délce 125 µs, jimiž se vyplní 1 ms rámec.
Po sběrnici se nepřenáší hodinový signál. Na začátku každého rámce se vysílá synchronizační signál. Na ten se všechna zařízení zasynchronizují a během přenosu zachovávají časování. Délka paketu může být 8 až 1024 bajtů. Samotný přenos dat se děje diferenciálně. To znamená, že různým logickým úrovním odpovídají stavy D+ na 3.3 V, D- na 0 V a D+ na 0 V, D- na 3.3 V. D+ i D- na úrovni 0 V znamenají reset sběrnice.
Kódování použité na sběrnici je NRZI (Non-Return to Zero Inverted) se vsouváním bitů (bit stuffing). NRZI funguje tak, že každá nula v datech vede ke změně úrovně. Jedničky nechávají logickou úroveň nezměněnou. Vsouvání bitů se uskutečňuje z důvodu hrozící ztráty synchronizace. Vsouvá se nula po každých šesti po sobě jdoucích jedničkách. Tím se vynutí změna úrovně přenosu. Vsunuté nuly se v přijímajícím zařízení opět odstraní, takže se nijak neprojeví. Sekvence bitů 0111111110, jak se fyzicky přenáší po sběrnici, je znázorněna na obrázku 2.2.

Obrázek 2.2: Přenos 0111111110 pomocí NRZI kódování a vsouvání bitů. Vsunutá nula je podtržená.

2.2 Přenos dat | 9

Přes USB lze připojit velmi širokou paletu zařízení, například myš, klávesnici, pevný disk, flash pamět’, digitální fotoaparát, tiskárnu nebo zvukovou kartu. Různé periferie mají rozdílné požadavky na přenos. Myš nebo klávesnice přenáší velmi málo dat, ale potřebují rychlou a pravidelnou odezvu. Flash pamět’ nebo tiskárna přenáší velké objemy dat, ale není potřeba krátkých přístupových dob. Zvuková karta potřebuje oboje. Rychlou odezvu i velkou datovou propustonost. Aby sběrnice zvládla všechny tyto různorodé požadavky, probíhá přenos několika typů. Každý má jiné vlastnosti a využívá jej jiná třída zařízení.
Bulk přenos je určen pro situace, kdy není důležitá přenosová rychlost ani odezva. Příklad je přenos souboru do tiskárny nebo skenování. Při tomto použití mohou přenosy v případě nutnosti počkat, pokud je sběrnice vytížená jinými typy přenosů, jež mají garantovanou přenosovou rychlost. Pokud sběrnice není vytížená, bulk přenos je velmi rychlý.
Interrupt přenos je určen pro zařízení, jež potřebují periodicky obsloužení od mastera sběrnice. Jedná se o jediný druh přenosu, kterým mohou komunikovat low speed zařízení. Klávesnice a myši používají iterrupt přenos k neustálému odesílání dat o pohybu kurzoru a zmáčknutých klávesách.
Izochronní přenosy mají garantovanou odezvu, ale na rozdíl od ostatních typů přenosů není zajištěna kontrola dat. Ostatní typy přenosů při chybě opakují transakci. V případě izochronního přenosu to vzhledem ke garantované odezvě není možné, takže zařízení musí být schopna vyrovnat se s malými chybami v datech. Izochronních přenosů využívají externí zvukové karty pro přenos dat, která mají výt přehrána v reálném čase. Občasná chyba v přenosu je v takovém případě snesitelnější než výpadek datového toku.
Posledním typ přenosu se nazývá kontrolní (control). Tento druh přenosu je určen výhradně pro mastera ke zjišt’ování specifikací připojených zařízení, nastavování jejich adres nebo vybírání konfigurací. Kontrolní přenos musí na rozdíl od všech ostatních typů podporovat každé USB zařízení. Ostatní typy přenosů jsou typické pro jistý druh periferií a není důvod, proč by tiskárna podporovala interrupt nebo izochronní přenos.
Všechny přenosy dat putují bud’ do tzv. koncového bodu (endpoint) nebo z něj. Koncový bod je obvykle tvořen blokem paměti nebo registrem v řídícím obvodu daného zařízení. Každý koncový bod přenáší data pouze v jednom směru. Koncových bodů může jedno high nebo full speed zařízení obsahovat až 32-16 vstupních (in) a 16 výstupních (out). Low speed zařízení jsou omezena pouze na dva endpointy. Vstupní a výstupní endpointy se posuzují podle master zařízení. Z hlediská softwaru se po inicializaci každý endpoint chová jako logická roura, která přenáší data daným typem přenosu a daným směrem. Od topologie rozbočovačů a zařízení je zcela abstrahováno.

10 | 3 Zvolená koncepce

# 3 Zvolená koncepce

Před započetím návrhu je vždy potřeba udělat rozvahu nad tím, jaké řešení bude použito. V případě komunikace po USB sběrnici jsem po jisté době hledaní zjistil, že existuje velmi široká paleta možností. Prakticky každý významnější výrobce elektroniky má svoje řešení. Někteří výrobci dodávají i několik různých způsobu, jak komunikaci zařídit. Pevné základy znalostí v tomto směru mi poskytly zejména knihy [12], [11] a známý vyhledávač Google. Většina komunikace je řešena tak, že příslušná firma vybavila některou svoji řadu již výráběných a ověřených mikroprocesorů SIE¹
jednotkou pro USB a přidala několik řídících registrů. Příklady takových řešní jsou 68HC05 68HC08 od Motoroly, PIC16C7x5 od Microchipu, Intel 8051UX od Standard Microsystems, AN2121 od Cypress Semiconductor, StrongARM od Intelu, ...
Tato řešení mají nevýhodu v tom, že obsluha USB rutin se musí naprogramovat do firmware mikroprocesoru. To jednak snižuje odezvu procesoru a to omezuje použití procesoru pro další měřící a řídící účely. Za druhé je pořeba znalost příslušného mikroprocesoru a způsobu jeho programování, což je v některých případech pouze assembler. A to je je krajně nepohodlný programovací jazyk. Výhodou řešení založených na mikroprocesoru je velká flexibilita.
Takovéto řešení není ideální pro cíle této práce. Cílem komunikace po USB sběrnici je pouze přenášet data. Přičemž struktura dat bude v podstatě libovolná díky tomu, že jej bude obsluhovat vlastní aplikace. Z toho důvodu není potřeba splňovat jakékoli podmínky na komunikaci pevně definované pro danou třídu USB zařízení jako třeba HID² pro myši nebo klávesnice a USB Mass Storage pro flashdisky.
Pro naše účely je daleko flexibilnějším řešením je speciální obvod, který převede USB do některého mikrokontroléry běžně používaného rozhraní například SPI, I²C, Microwire nebo USART. Takovýchto obvodů je k dispozici spousta od různých výrobců například USBN9603 od National Semiconductor, PDIUSB od Philips, FT232 od FTDI,...
Rozhodl jsem se pro obvod FT232R od firmy FTDI. Důvodů pro toto rozhodnutí je několik. Prvním je snadná dostupnost na českém trhu a druhá je převod na USART rozhraní. To jsou klíčové vlastnosti, které značně usnadňují použití.
Dalším důvodem je široká multiplatformnost dodávaných ovladačů. Pokryty jsou snad všechny dnes myslitelné platformy včetně Windows Mobile pro PDA zařízení. Mimo proprietátních ovladačů s uzavřeným zdrojovým kódem je k dispozici i ovladač v licenci GPL s názvem Libftdi.
V neposlední řadě je potřeba započítat kvalitu a dostupnost dokumentace dokonce i v češtině. Kniha [10] mi byla cenným zdrojem inspirace po koncepční stránce v kapitole 10 je

1
Jednotka sériového rozhraní (Serial Interface Engine).
2Zařízení lidského rozhraní (Human Interface Device).

11

navrženo podstatně jednodušší nicméně koncepčně velmi podobné zařízení. Nevýhodou knihy
[10] je skutečnost, že používá předchozí generaci obvodu FT232B, který se zapojuje odlišně než současné generace FT232R, a vyžaduje několik podpůrných součástek. Tím pádem se kniha hodí spíše pro inspiraci ve fázi návrhu než, ža by byla zdrojem zapojovacích schémat. Dalším obvodem, který je potřeba zvolit je srdce celé aplikace - řídící mikrokontrolér. Jeko úkolem bude posílat hodnoty vstupů obvodu FT232R a zároveň přijímat příkazy k nastavení výstupů. V podstatě jsou možné dva přístupy. Malý mikroprocesor s velkým množství připojených periferií nebo velký mikroprocesor, který ma již vše potřebné vestavěno. Zvolil jsem druhou variantu, protože umožňuje rychlejší vývoj a snadnější modifikovatelnost. Volba mikroprocesoru je komplikovaný problém a striktně vzato nemá správnou odpověd’. Na trhu existuje spousta výrobců nabízejících své mikrokontroléry. Nejvhodnější volbou se po průzkumu trhu shledal 8-bitové mikroprocesory firmy Atmel. Jsou navrženy s ohledem na programování primárně v jazyce C, které je daleko pohodlnější než assembler. Konkurenční 8-bitové mikroprocesory od firmy Freescale nebo Microchip mají v podstatě shodné vlastnosti. Nicméně jejich návrh od počátku nepočítá s vývojem firmware ve vyšších programovacích jazycích. Tato vlastnost byla dodělána dodatečně. To spolu s omezenější instrukční sadou způsobuje, že při stejné frekvenci se stejný kód neprovadí stejně rychle.
Pro mikroprocesory firmy Atmel existuje mimo upravené verze populárního kompilátoru gcc i sada vývojových nástrojů se svobodnou licencí. To rozhodně nelze říct o všech na trhu dostupných mikroprocesorech, kde licenční poplatky za vývojové nástroje dosahují nemalých částek. Instalační program svobodného vývojového prostředí WinAVR je k dispozici na doprovodném CD. Mimo něj je možné k vývoji použít AVR Studio od samotné firmy Atmel i s proprietárním kompilátorem.
Jedná-li se o samotné vstupy a výstupy modulu je vhodné je nějakým způsobem ošetřit. Vyvádět přímo nožičky mikroprocesoru je poměrně riskantni, jelikož chyba zapojení vnějších zařízení může vyřadit celou měřící desku. Proto je vhodné digitální vstupy galvanicky oddělit. Ideální volbou jsou optovazby. Mimo šumově eliminačních vlastností disponují průrazným napětím v řádu kV.
Pro digitální a PWM³ výstupy, které mají být schopny snášet výkonovou zátěž, je vhodné ošetřit jejich výstupy nějakým druhem zesilovače. Nejvhodnějším řešením je výkonový darlingtonový tranzistor spínaný proti vnější výkonové zemi, jehož kolektor vyvedeme jako výstup.
Jedním ze způsobů, jak ošetřit analogové vstupy, je speciální typ optovazby s lineárním přenosem. To ovšem přináší komplikace s napájením. Není dost dobře možné nápajet jedním vodičem logiku a zároveň na stejném vodiči měřit analogový signál. Vnější napájení by zkomplikovalo použití analogových vstupu do té míry, že jsem se rozhodl od ošetření analogových vstupů upustit.
Blokové schéma navrhovaného zařízení je na obrázku 3.

3Pulzně šířková modulace (Pulse Width Modulation)

12 | 3 Zvolená koncepce

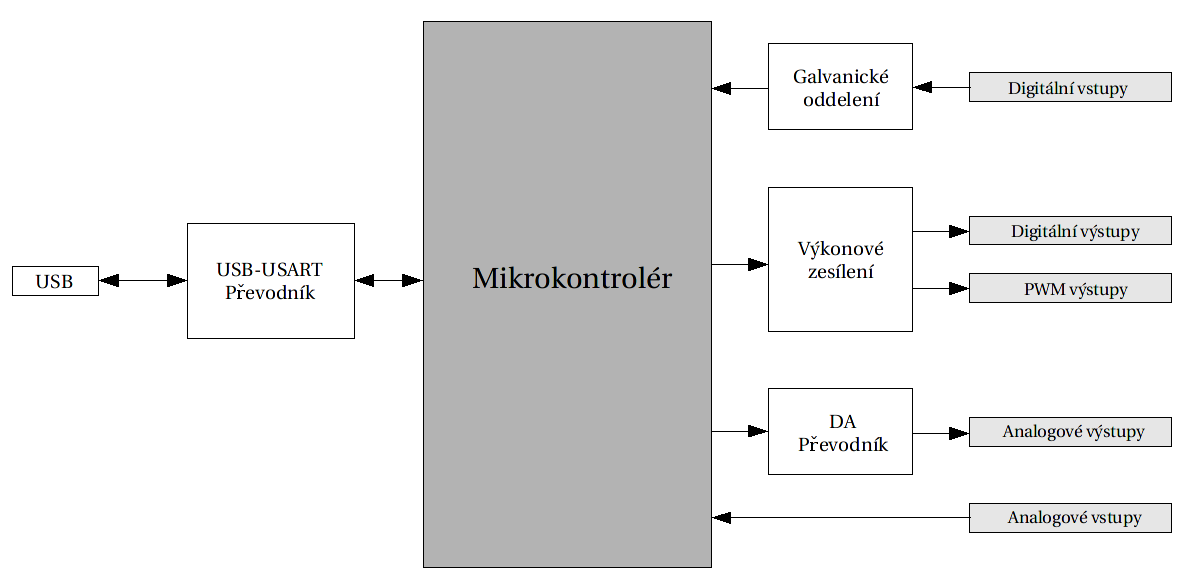
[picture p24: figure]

Obrázek 3.1: Blokové schéma navrhovaného zařízení.

13

# 4 Použité integrované obvody

## 4.1 FT232R - USB USART převodník

Jak napovídá název obvodu, jeho hlavní využití spočívá v převodu mezi sériovým rozhraním a USB. Zjednodušeně řečeno, z jedné strany se do čipu přivedou datové vodiče USB a z druhé strany je sériové rozhraní. Zbytek zařídili inženýři, kteří obvod navrhovali. Jediný problém, který obvod dělí od úplné kompatibility s RS232, je nízká napět’ová úroveň vývodů daná 5 V napájecím napětím na USB sběrnici. Připojením převodníku urovní MAX232 lze tuto obtíž jednoduše vyřešit. Tím získáme velmi snadno převodník z USB na sériový port včetně správných napět’ových úrovní.
Obvod se vyrábí ve dvou verzích FT232RL a FT232RQ. Obě varianty se liší pouze pouzdrem. FT232RL se dodává v SSOP-28 a FT232RQ v QFN-32. Fotka pouzdra SSOP-28 FT232RL je na obrázku 4.1.

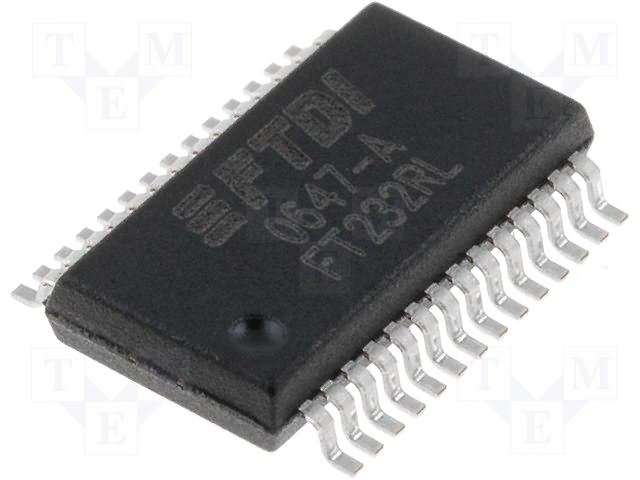
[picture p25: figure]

Obrázek 4.1: Převodník FT232RL.

Sériové rozhraní čipu je opatřeno všemi běžně využívanými vlastnostmi. Lze měnit počet datových bitů a stop bitů, kontrolovat sudost nebo lichost parity, existuje možnost volby XON/XOFF, DTR/DSR, RTS/CTS nebo žádného hardwarového řízení toku. Zařízení je opatřeno 256 bytovou přijímací a 128 bytovou odesílací FIFO vyrovnávací pamětí. Přenosové rychlosti sériového rozhraní je možné vybírat z intervalu 300 Bd až 1 MBd.
Oproti předchozí generaci označované jako FT232B obvod doznal řady podstatných změn a vylepšení. Nejviditelnější změnou je absence vnějšího krystalu, EEPROM a pro USB charakteristického 1.5 kΩ pull-up rezistoru. Všechny součástky jsou integrovány uvnitř čipu, což zlevňuje konstrukci a zjednodušuje návrh plošných spojů.
Další novinkou je FTDIChip-IDTM, což je unikátní seriové číslo zapsané do každého vyrobeného obvodu. Toto číslo se nedá uživatelsky změnit. To umožňuje obvod použít jako součást ochrany proti kopírování komerčního software.
Na první pohled nedůležitou schopností obvodu se může zdát BitBang režim. V tomto režimu se mohou linky modemu změnit v paralelní vstupně-výstupní port. K dispozici je syn-

14 | 4 Použité integrované obvody

chronní¹ a asynchronní² přenos. Díky tomuto režimu je možné jednodušší periferie navrhnout bez použití řídícího mikroprocesoru.

Jedná-li se o software, tak výrobce obvodu dává k dispozici na svém webu dva typy ovladačů. Prvním je VCP, což je zkratka pro Virual Communication Port. Tento ovladač neumožňuje využití některých pokročilých funkcí. Na druhou stranu umožňuje převod již existujících aplikací, jež využívají služeb sériového portu na sběrnici USB, bez nutnosti výrazných změn v obslužné aplikaci. Ovladač pracuje tak, že v systému vytvoří virtuální sériový port, ke kterému lze přistupovat pomocí standartních funkcí daného operačního systému pro přístup k zařízení. Tento ovladač je dle [1] k dispozici pro operační systémy Windows 98, 98SE, ME, 2000, Server 2003, XP, Server 2008, XP, XP 64-bit, XP Embedded, Vista, Vista 64-bit, CE 4.2, 5.0 a 6.0, Mac OS 8/9/X a Linux ≥ 2.4.

Další typ ovladače má název D2XX. Tento ovladač umožňuje využití všech funkcí obvodu FT232R, včetně přistupu do EEPROM a režimu BitBang. Spolu s ovladačem pro příslušný operační systém se dodává i dynamicky linkovaná knihovna s funkcemi, které aplikace využívají. Jeho podstatnou nevýhodou je uzavřený vývoj. Výrobce nedává k dispozici zdrojové kódy. Tento ovladač je dle [1] k dispozici pro operační systémy Windows 98, 98SE, ME, 2000, Server 2003, XP, Server 2008, XP, XP 64-bit, XP Embedded, Vista, Vista 64-bit, CE 4.2, 5.0 a 6.0 a Linux ≥ 2.4.

V této práci je preferovaný způsob komunikace knihovna s názvem Libftdi. Tento ovladač ke své funkci používá Libusb 0.1. Libusb je knihovna pro přístup k USB zařízením, která se snaží nabídnout API³
funkce nezávislé na operačním systému. Tím pádem není potřeba pro každý operační systém psát kód pro jeho jádro. To je technologicky a časově mnohem náročnější, než napsat ovladač pouze jednou, a pak jej jednoduše překompilovat pod jiným operačním systémem. Libftdi je k dispozici na platfomách, pro něž existuje port Libusb. To jest Linux, Mac OS X, Darwin, 32-bitové Windows, NetBSD, FreeBSD a OpenBSD. Jak libusb, tak libftdi je svobodný software v licenci GPL. Tím pádem je k dispozici zdrojový kód, který je možné libovolně měnit a zkoumat jeho fungování bez porušení jakýchkoliv licenčních smluv.

## 4.2 UMS3 - DIP-24 USB USART převodník

Modul UMS3 od firmy Asix je založen na čipu FT232R. Mimo samotného obvodu FT232R se na plošném spoji nacházejí pouze filtrační kondenzátory na napájecích vstupech VCC, VIO a 3V3OUT, jak je patrné z obrázku 4.2. Hlavní výhodou modulu je snadná manipulace a používání. Nevýhodou je několikanásobně vyšší cena ve srovnání s obvodem FT232R. Plošný spoj modulu je navržen tak, že vývody jsou rozměrově kompatibilní s pouzdrem DIP-24. Toto pouzdro umožňuje mimo jiné značně jednodušší pájení nebo použití v kontaktních polích, což by šlo jen velmi těžko s malými SSOP-28 nebo ještě hůře s QFN-32 pouzdry, v nichž se čip FT232R dodává.

1Zápis i čtení probíhá zároveň.
2Zápis a čtení jsou nezávislé.
3Aplikační programové rozhraní (Application Programming Interface)

4.3 MCP4922 - Dvojkanálový D/A převodník | 15

Obrázek 4.2: Modul UMS3.

## 4.3 MCP4922 - Dvojkanálový D/A převodník

Obvod MCP4922 vyrábí firma Microchip. Jedná se digitálně analogový převodník se dvěma analogovými kanály a 12-bitovým rozlišením. Typická doba ustalování výstupního napětí je 4.5 µs. Převodník pracuje na principu rezistorové kaskády zapojené jako dělič napětí. Výstupní napětí VOUT může mít díky integrovanému zesilovači referenčního napětí VREF velikosti až 2VREF . Výstupní napětí se řídí vztahem

VOUT = G

VREF D
2
12 | . | (4.1)

G značí zesílení a nabývá hodnot ×1 nebo ×2. D je digitální hodnota poslaná převodníku. Diferenciální nelinearita dosahuje nejvýše hodnoty ±0.2 LSB⁴
| | , integrální nelinearita ±2 LSB
[5, str 2]. Na výstup převodníku je možné připojit interní zesilovač zapojený jako sledovač. Díky tomu se dramaticky zvýší vstupní impedance a omezí se oscilace při použití zátěže s vysokou kapacitou. Pokud se zesilovač nepoužije, je vstupní impedance převodníku 167 kΩ/ 7 pF [5, str 2]. Omezení napětí a offset nulové hodnoty při použití výstupního zesilovače jsou velmi malé. Přesné hodnoty lze najít v [5].
Komunikace s převodníkem probíhá po sběrnici SPITM5 s maximální hodinovou frekvencí 20 MHz. Průběh signálu a pořadí bitů v řídící sekvenci je na obrázku 4.3.

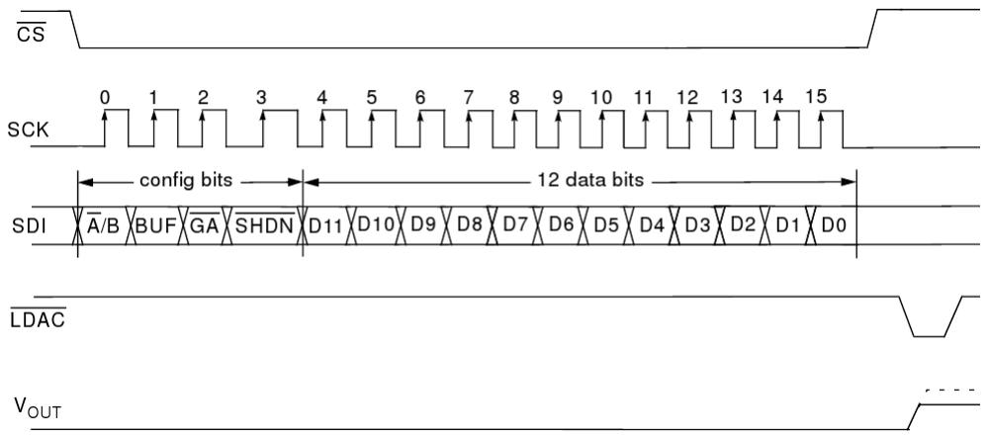
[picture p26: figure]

Obrázek 4.3: Přenos dat D/A převodníku MCP4922.

CS⁶

signál slouží k vybrání převodníku pro komunikaci. SPITM sběrnice umožňuje připojení více zařízení. Pomocí CS se vybírá, které zařízení na sběrnici bude přijímat následující vysílaná

4Nejméně významný bit (Least Significant Bit).
5Sériové rozhraní pro periferie (Serial Peripheral Interface).
6Výběr čipu (Chip Select).

16 | 4 Použité integrované obvody

data. SCK⁷
je hodinový signál sběrnice.
Po SDI⁸ proudí data. Jejich struktura je
- A/B Bit sloužící pro výběr výstupu, pro který budou platit následující data.
- BUF Připojení nebo odpojení výstupního zesilovače a tím pádem i volba impedance výstupu.
- GA Invertovaná hodnota zesílení referenčního napětí. Pro G z rovnice 4.1 platí vztah G = GA + 1.
- SHDN Softwarové vypnutí převodníku kvůli snížení spotřeby. Mimo tento druh vypnutí má obvod ještě nožičku sloužící ke stejnému účelu se shodným názvem. Vypnutí pomocí vývodu umožuje odpojit i přenosovou logiku SPITM rozhraní a snížit spotřebu proudu na 1.5 µA. Softwarové vypnutí má spotřebu 5 µA.
- D11..D0 12-bitové číslo určené k převodu na napětí podle rovnice 4.1.

LDAC vývod na převodníku umožňuje po předchozím sériovém odeslání dvou digitálních hodnot pro oba kanály současné přivedení napětí na oba výstupy.
Další detaily ohledně časových přesahů nebo náběžných a sestupných dob nutné k správnému naprogramování komunikace lze nalézt v [5, str 6].

## 4.4 ATmega1280 - Osmibitový RISC mikroprocesor

Mikroprocesor ATmega 1280 je výrobkem firmy Atmel. Jedná se o osmibitový RISC⁹ mikroprocesor. Paleta jeho vlastností a fukcí je velmi pestrá a široká. Podrobný popis všech vlastností je k dispozici v [3].
Procesor je vybaven 16 multiplexovanými A/D převodními kanály s převodníkem o rozlišení 10 bitů. Dále obvod obsahuje čtyři nezávislé 16 bitové časovače schopné generovat PWM signál. Dalšími důležitými vlastnostmi je maximální povolená taktovací frekvence 16MHz. Některé z portů jsou opatřeny logikou pro komunikaci po známých sběrnicích jako USART, SPI, nebo I²C či Microwire.


Obrázek 4.4: Fotka mikroprocesoru ATmega1280-16AU

7Sériový hodinový signál (Serial Clock).
8Sériová data dovnitř (Serial Data In).
9Počítač s redukovanou instrukční sadou (Reduced Instruction Set Computer).

4.5 ATmega168 - Osmibitový RISC mikroprocesor | 17

## 4.5 ATmega168 - Osmibitový RISC mikroprocesor

Mikroprocesor ATmega168 má shodnou instrukční sadu a jeho kód je binárně kompatibilní s procesorem ATmega1280. Rozdíl mezi oběma obvody je pouze v počtu zastoupení jednotlivých funkcí. Výhodou mikroprocesoru je, že se dodává i v DIP-28 pouzdře, které je použitelné při vývoji v kontaktním nepájivém poli. Detailní specifikace mikroprocesoru lze nalézt v [4].


Obrázek 4.5: Fotka mikroprocesoru ATmega168-20PU

## 4.6 PC849 - Ctyřnásobná analogová optovazba ˇ

Optovazbu PC849 vyrábí firma Sharp. Ze schématu zapojení integrovaného obvodu na obrázku 4.6 je patrné, jak optovazba pracuje. Na jedná straně je LED dioda, která vyzařuje v infračerveném spektru, a na straně druhé je fototranzistor. Kolektorový proud je řízen množstvím dopadajícího světla a to je učeno proudem procházejícím LED diodou. Diody a fototranzistory jsou v DIP-16 pouzdře integrovaného obvodu PC849 umístěny čtyři. Hlavní charakteristikou optovazby je převodní poměr CT R

10 mezi proudem tekoucím
diodou IF a kolektorovým proudem IC.
IC = CT RIF | (4.2)

Optočlen PC849 má CT R v rozmezí 50% až 400%. Typicky je však tato hodnota mezi 100% a 140% podle [7, str 3].
Uspořádání optovazby umožňuje galvanicky oddělit větve obvodu s různými potenciály nebo impedancemi a zároveň je schopno přenášet signál. Výhodou optického přenosu je mimo galvanického oddělení ještě eliminace šumu a ochrana proti přepětí. Optovazba PC849 je schopna vydržet bez proražení rozdíl potenciálů až 5 kV po dobu jedné minuty. Nevýhoda optovazby je zpoždění signálu a neschopnost přenášet vysoké frekvence. Typická doba reakce na změnu signálu na vstupní diodě je zhruba 5 µs. Detaily lze najít v [7, str 3].

## 4.7 6N134 - Dvojnásobná optovazba pro přenos digitálních dat

Optovazba je výrobkem firmy Hewlett-Packard. Schéma a fotografie obvodu jsou na obrázku
4.7. Místo fototranzistoru, který obsajuje výstup PC849, je 6N134 na výstupech vybaven negovaným hradlem CMOS úrovně. Díky tomu se dá dosahovat přenosových rychlostí až

10Proudový převodní poměr (Current Transfer Ratio).

18 | 4 Použité integrované obvody


Obrázek 4.6: Fotka a schéma optovazby PC849.

10 Mbit/s. Výstup je na logické jedničce pokud proud vstupní LED diodou je menší než 250 µA a na logické 0, jestliže je tento proud v rozmezí 10 mA až 20 mA. Průrazné napětí optočlenu je 1.5 kV.


Obrázek 4.7: Schéma a fotka 6N134 v DIP-16 pouzdře.

## 4.8 ULN2803A - Osmikanálové darlingtonové pole

Známý integrovaný obvod ULN2803A tvoří 8 NPN darlingtonových tranzistorových párů. Schéma a fotografie obvodu jsou na obrázku 4.8. Vstupy obvodu jsou opatřeny hradlem, jež je schopno komunikovat se logickými úrovněmi TTL a CMOS. Každý výstup je zatižitelný proudem 500 mA a napětím 30 V. Zátěž může mít indukční charakter, protože v obvodu jsou obsažený i ochrané diody pro každý výstup. Změna úrovně trvá typicky 10 ns.

## 4.9 ULN2064B - Ctyřkanálové darlingtonové pole ˇ

Obvod ULN2064B je navržen prakticky stejně jako ULN2803A. Pracuje s TTL nebo CMOS vstupem. Pouze výstupy jsou schopny většího výkonového zatížení. Každý ze čtyř darlingtovnových tranzistorů obsažených v obvodu je schopen dodávat proud do 1.5 A pod napětím 30 V. Schéma obvodu je na obrázku 4.9. Změna úrovně zabere obvodu obvykle 1.5 µs.

4.10 LM385 - Napět’ová reference 2.5 V | 19


Obrázek 4.8: Fotka a schéma darlingtonového pole ULN2803A


Obrázek 4.9: Schéma darlingtonového pole ULN2064B

## 4.10 LM385 - Napět’ová reference 2.5 V

LM385 je napět’ová referenční dioda s výstupním napětím 2.5 V . Tolerance referenčního napětí je 1%. Pracovní proudy se pohybují v rozmezí 10 µA až 20 mA. Výstupní impedance má velikost do 1.5 Ω a teplotní drift je 20 ppm/

◦C
11. Dioda je vyfocena na obrázku 4.10.

Obrázek 4.10: Fotka napět’ové referenční diody LM385.

11Cást z milionu (Part Per Milion). ˇ

20 | 5 Prototyp

# 5 Prototyp

## 5.1 ATmega168 UMS3

Před samotnou stavbou konečné verze zařízení jsem se rozhodl v kontaktním nepájivém poli postavit zjednodušenou verzi měřící desky. Kontaktní pole umožňuje velmi rychle přidávat a odebírat součástky a změnit zapojení, pokud něco nefunguje. To na tištěném spoji není dost dobře možné. Na zjednodušené verzi jsem vyvinul, odladil a otestoval software pro PC a firmware pro mikrokontrolér. Firmware jsem psal tak, aby šel jednoduše rozšířit pro konečnou verzi desky s větším mikroprocesorem.
Schéma a fotka zařízení, které jsem postavil na kontaktním nepájivém poli, je na obrázku
5.1. Jako řídící jednotku jsem použil mikroprocesor ATmega168 od Atmelu. Důvod pro použití tohoto mikroprocesoru je jeho DIP-28 pouzdro, které je vhodné pro zasunutí do nepájivého pole. Mikroprocesor ATmega1280 zapájený v konečné verzi měřící desky se v DIP pouzdře nevyrábí. Oba procesory mají stejnou instrukční sadu. Takže není problém přenášet mezi nimi napsaný kód. Pokud se týká funkcí, tak ATmega168 má všechny použíté vlastnosti. Rozdíl je pouze v jejich počtu. Mikroprocesor je taktován externím krystalem na 20 MHz.
A/D převodník integrovaný v mikroprocesoru umožňuje volbu z několika napět’ových referencí. Je možné použít VCC, vstup pro referenční napětí AREF nebo interní 1.1 V napětí. Vstupy jsou zapojeny k různým zdrojům napětí, aby bylo možno zkontrolovat jejich správnou funkčnost. Jsou připojeny výstupy D/A převodníku, napět’ová reference, potenciometr zapojený jako dělič napět’í a 3.3 V výstupní napětí modulu UMS3.
Převod USB na sériové rozhraní obstarává modul UMS3, v němž je zapájen obvod FT232R. Na příslušné vývody modulu jsou připojeny LED diody signalizujích příjem a odesílaní dat spolu s rezistory 330 Ω omezujícím proud diodami, aby nedošlo k jejich spálení. Sériové rozhraní UMS3 je připojeno na USART jednotku mikroprocesoru. Při komunikaci je použito hardwarové řízení toku pomocí modemových signálu RTS/CTS, aby nedošlo k přetečení vyrovnávacích FIFO pamětí na obou stranách.
Jako zdroj referenčního napětí 2.5 V pro převodníky A/D a D/A je použitá dioda LM385 s rezistorem 2.5 kΩ, který omezuje procházející proud na 1 mA.
D/A převodník MCP4922 je připojen přes SPI rozhrání k mikroprocesoru, který mu posílá řídící sekvence. Z důvodu nedostatku nožiček mikrokontroléru ATmega168 nejsou zapojeny vstupy SHDN a LDAC. SHDN je připojen na VCC a SHDN na GND. Nicméně kód pro režim USB suspend byl otestován, když byl signál SHDN přiveden místo jednoho z digitálních vstupů. Výstupy D/A převodníku jsou připojeny na vstupy A/D převodníku, aby bylo možno kontrolovat funkčnost.
Neocenitelnou pomocí při ladění kódu pro přenos dat k D/A převodníku po SPI sběrnici byl pamět’ový čtyřkanálový osciloskop LeCroy z Elektronického praktika. S jeho pomocí se velmi rychle dařilo opravovat chyby v kódu, které by jinak byly mnohem hůře odhalitelné.


5.1 ATmega168 UMS3 | 21

Obrázek 5.1: Schéma a fotka prototypu s mikroprocesorem ATmega168.

22 | 5 Prototyp


Obrázek 5.2: Osciloskopem zachycený přenos řídící sekvence pro D/A převodník.

Změřená podoba řídící sekvence z obrázku 4.3 je znázorněna na obrázku 5.1.
Další obvod, který se nachází na prototypu, je výkonový stupeň ULN2803A. Napájení výkonového zesílení je řešeno z USB sběrnice stejně jako napájení celé aplikace. To, že chybí výkonější externí zdroj není pro testování funkčnosti na škodu. K vstupům výkonového stupně jsou připojeny dva vývody mikroprocesoru. Jeden z nich slouží jako PWM a druhý, jako digitální výstup. Zátěž představují LED diody s rezistory omezujícími proud.
Dále deska obsahuje optovazbu 6N134, která ošetřuje dva digitální vstupy. Vstupní proud optovazby je omezen 100 Ω rezistorem. Spínání digitálních vstupů je řešeno vypínačovým polem. Spínače jsou zapínány proti zemi. Pokud jsou spínače rozepnuté, tak je signál tažen vzhůru na VCC 10 kΩ pull-up rezistorem.
Před sestavením prototypu s mikroprocesorem ATmega168 jsem postavil několik jiných obvodů, které sloužily převážně k otestování BitBang režimu čipu FT232R. Fotografie, zapojovací schémata a kontrolní aplikace těchto obvodů lze nalézt na doprovodném CD.
Při tomto testování mně napadlo, že by se BitBang režim obvodu mohl využít k programování mikrokontroléru. Běžně se procesory ATmega programují přímo v aplikaci pomocí vyvedení ISP¹ konektoru, kam se připojí externí programátor. Využití BitBang režimu by eliminovalo externí programátor, čímž by se zvýšila pohodlnost použítí a flexibilita měřící desky. Taktéž by se snížily náklady na vývoj.
Nepříjemné bylo zjištění, že jsem nebyl první, kdo s touto myšlenkou přišel. Dokonce už existuje několik aplikací schopných mikrokontoléry pomocí BitBang režimu programovat. To po chvíli přemýšlení trošku zmírnilo mé rozladění, jelikož nejsem nucen do všech detailů studovat ISP programovací protokol a psát vlastní software.
Existuje patch na populární programovací nástroj Avrdude, který přidává nový typ programátoru schopného obsluhovat obovod FT232R. Aplikace patche a kompilování ze zdrojových kódů není pro běžné použití ideální a ne každý je toho schopen. Výhodou ale je, že se jedná o svobodný software s otevřeným zdrojovým kódem.
Dalším programem schopným zapsat program do FLASH paměti mikroprocesoru Atmel

1Programování v rámci systému (In System Programming).

5.1 ATmega168 UMS3 | 23

se jmenuje Ftisp. Jedná se o freeware využívající proprietární D2XX ovladače, které je nutné mít nainstalované, což je mnou považováno za nevýhodu. K dispozici je verze pro 32-bitové Windows, Mac OS X a Linux. Použití je velmi jednoduché. Po spuštění bez parametrů se zobrazí nápověda. Program se nachází na doprovodném CD.
Programování probíhá po modemových signálech DTR, DSR, DCD a RI. Zapojení k jednotlivým linkám ISP rozhraní na mikroprocesoru je patrné z obrázku 5.1.

24 | 6 USB měřící deska

# 6 USB měřící deska

Schéma zapojení konečné verze měřící desky je na obrázku 6.3. Podoba plošného spoje je na obrázku 6.6. Z důvodu přehlednosti nejsou napsány hodnoty odpovídajících veličin jednotlivých součástek přímo ve schématu, ale nacházejí se v tabulce 6.1.
Rídícím obvodem měřící desky je mikroprocesor ATmega1280. K mikroprocesoru jsou ˇ připojeny ostatní podpůrné obvody, které zesilují nebo chrání jeho vstupy nebo výstupy, popřípadě zajišt’ují komunikaci po USB sběrnici.

Sluší se dodat, že původní volba řídícího mikroprocesoru padla na novou modelovou řadu firmy Atmel s názvem Xmega. Konkrétně na model ATXmega128A1. Tento mikroprocesor má mimo jiné 16 integrovaných 12-bitových A/D převodníků a 4 12-bitové D/A převodníky. Využití tohoto procesoru zabránila jeho nedostupnost na trhu v době psaní práce.

Programování mikroprocesoru je vyřešeno stejným způsobem, jako v případě prototypu na kontaktním nepájivém poli - pomocí modemových linek BitBang režimu obvodu FT232R.

## 6.1 Digitální výstupy

Měřící deska obsahuje 16 digitálních výstupů. Výstupy jsou označeny na spodní straně desky jako DIG OUT-#. Na každý z výstupů mikroprocesoru je připojen darlingtonový zesilovací tranzistor. Jak je patrné ze schématu 6.3 ne všechny výstupy jsou opatřeny stejným výkonovým zesílením. Ctyři z výstupů jsou zapojeny přes výkonější pole ULN2064B, takže ˇ mohou snášet výkonové zatížení do 1.5 A. Tyto výstupy lze poznat tak, že jsou opatřeny robustnějším konektorem počítačového typu LO1. Robustnější konektory jsou na měřící desce používány jednak, protože lépe vedou velké proudy a také proto, aby nešlo zaměnit zařízení koncipované pro větší zátěž a připojit jej na výstup, který není dostatečně dimenzován.

Ostatní výstupy jsou ošetřeny tranzistorovým polem ULN2803A, takže jsou schopny kontolovat proudovou zátěž o velikosti 500 mA. Výsupy jsou opatřeny taktéž konektory počítačového typu, ale menších rozměrů. Jsou označeny SO1 a SO3.

Digitální výstupy jspu realizovány vyvedením kolektoru výkonového tranzistoru. Zátěž je spínána proti vnější výkonové zemi, která je pro pohodlí přivedena do desky konektorem pro vnější napájecí zdroj CON1. Na desce je rozmístěno několik konektorů, přes které lze připojovat zátěž. Jejich označení je SO4, SO5 a LO4. Ze spodní strany desky v místě příslušného konektoru je označení, na který kolík je přiveden větší (+) a na který menší (-) potenciál.

6.2 PWM výstupy | 25

## 6.2 PWM výstupy

PWM výstupy jsou realizovány stejně jako digitální výstupy pomocí kolektoru výkonového tranzistoru. Polovina z osmi PWM výstupů je opatřena výkonovým zesilovačem ULN2064B a druhá polovina je ošetřena obvodem ULN2803A. Z toho plynou maximální přípustné proudové zátěže 1.5 A respektive 500 mA.
Charakteristická doba reakce výstupů obvodu ULN2064B je 1.5 µs. Z toho je možné odvodit, že nosná frekvence použitá při generování PWM pulzů by neměla přesáhnout hodnotu zhruba 100 kHz. Reakční doba obvodu ULN2803 je podstatně lepších 10 ns. To limituje frekvenci PWM taktem použitého mikroprocesoru. Ten dosahuje hodnoty 16 MHz. Digitální i PWM výstupy jsou ošetřeny proti zkratu osazením patice na pojistky 5×20 mm označené F1. Výkonově zatížitelné spoje jsou na desce plošného spoje vyvedeny ve větší šířce, aby lépe snášely proudovou zátěž.

## 6.3 Analogové výstupy

Analogové výstupy desky jsou realizovány pomocí D/A převodníku MCP4922. Rozsah převáděného napětí je stejný jako referenční napětí 2.5 V. Mimo to je díky zesilovači referenčního napětí ×2 možné rozšířit rozsah až na 5.0 V. Převodník pracuje s rozlišením 12-bitů. Výstupy převodníku jsou vyvedeny na konektor IL1. Spolu se dvěma výstupy převodníku je na konektor ještě vyvedena napět’ová reference a zem.

## 6.4 Digitální vstupy

Měřící deska je osazena 16 digitálními vstupy. Digitální vstupy jsou ze spodní strany desky tištěného spoje označeny DIG IN-#. Vstupy jsou realizovány konektory typu MLW označenými jako SI1 a SI2. Použití těchto konektorů umožňuje samostatné vyvedení anody a katody z každé diody v optovazbě. Tím je umožněna velká flexibilita při připojování. Není nutné se vázat na společnou zem pro všechny vstupy.
Každý z digitálních vstupů je opatřen optovazbou a rezistorem spočítaným tak, že vstup je TTL úrovně. Odpor je jednoduše spočítán podle Ohmova zákona.

R5−12,15−22 =

V

H
T T L − VD
IF

(6.1)

Chceme-li, aby proud vstupní diodou IF byl 20 mA při TTL napětí logické 1 V

H
T T L =
3.3 V, dostáváme při započtení napět’ového úbytku na diodě VD = 1.5 V, který je pro 6N134 prakticky stejný jako pro PC849 - zhruba 90 Ω.
Paralelně k diodám integrovaným v optovazbách jsou připojeny diody 1N4148 chránící vstup při prohození polarity.
Digitální optovazby 6N134 připojené ke konektoru SI1 a ze spodní strany označené jako DIG IN-1 jsou na výstupu opatřeny hradlem a umožňují přenos v podstatě na limitu taktu procesoru rychlostí 10 Mbit/s. Výstup hradle je negován. To znamená, že je-li vstup na logické 1, výstup je ve stavu logické 0.
Analogové optočleny PC849 vstupu DIG IN-2, které jsou připojeny ke konektoru SI2, hradlo na výstupu nemají. Výstup je zajištěn pomocí 30 − 50 kΩ pull-up rezistoru integrovaného uvnitř mikroprocesoru ATmega1280. To znamená, že jestliže vstupem teče proud

26 | 6 USB měřící deska


Obrázek 6.1: Schéma konečné verze.

6.4 Digitální vstupy | 27


28 | 6 USB měřící deska
Označení | Pouzdro | Hodnota | Množství
AI1,AI2 | MLW10 | Konektor | 2
C1,C2 | C-0805K | 12-22pF | 2
C13 | C-0805K | 10nF | 1
C14 | C-2817E | 470nF | 1
C3-12, C15-27 | C-0805K | 100nF | 23
CON1 | PCB-2.3mm | Napájecí Konektor | 1
D1-16 | D-0805 | Dioda 1N4148 | 16
F1 | F-5x20mm | Pojistka 1.5A | 1
IC1 | TQFP-100 | Atmega1280-16AU | 1
IC2 | SSOP-28 | FT232RL | 1
IC3 | DIP-14 | MCP4922D | 1
IC4 | TO-92 | CLM385N | 1
IC5, IC6 | DIP-16 | ULN2064B | 2
IC7, IC8 | DIP-18 | ULN2803A | 2
IL1, SO1, SO2 | PSH02-04WG | Konektor | 3
L1, L2 | FB-TH 3.5mm | Feritová perlička | 2
LO1, LO2 | PSH04-04WG | Konektor | 2
LO3 | PSH04-02WG | Konektor | 1
OK1, OK2 | DIP-16 | PC849 | 2
OK3-6 | DIP-16 | 6N134D | 4
Q1 | HC49S | Krystal 16MHz | 1
R1, R2 | R-0805 | 330 Ω | 2
R13 | R-0805 | 2.5 kΩ | 1
R3, R4, R14 | R-0805 | 10 kΩ | 3
R5-12, R15-22 | R-0805 | 90 Ω | 16
RXLED, TXLED | LED-3mm | LED | 2
SI1, SI2 | MLW16 | Konektor | 2
SO3 | PSH02-08WG | Konektor | 1
SO4, SO5 | PSH02-02WG | Konektor | 2
USB1 | USB-PTH | Konektor USB | 1
X0-7 | SMB-M | Stíněný konektor | 8

Tabulka 6.1: Seznam součástek a jejich označení.

6.5 Analogové vstupy | 29

(logická 1), je fototranzistor sepnut a vstup mikroprocesoru je na logické 0. Pokud je vstup ve stavu logické 0 (neteče proud), tak je odpor tranzistoru daleko větší než odpor 30 − 50 kΩ pull-up rezistoru a vstup mikroprocesoru je tím pádem vytažen na logickou 1. Přenosová rychlost optovazby PC849 je limitována její odezvou v délce 5 µs.

## 6.5 Analogové vstupy

Analogové vstupy jsou realizovány pomocí 10-bitových A/D převodníků integrovaných v mikroprocesoru ATmega1280. Referenční napětí může být opět bráno z několika různých zdrojů v rozsahu 1.1 V až 5 V. Cást vstupních konektorů je typu SMB. Tyto konektory ˇ umožňuji připojení stíněných kabelů, které jsou schopny omezit rušení citlivých signálů. SMB konektory jsou připojeny na vstupy 0-3 a 8-11. Tyto vstupy je možné při diferenciálním zapojení zesílit ×1, ×10 nebo ×200. Roli negativního terminálu hrají vstupy 1 a 9. Ostatní analogové vstupy jsou přivedeny na konektor typu MLW, který již není stíněn. Nevyužité piny v konektoru jsou připojeny na zem.
Maximální vzorkovací frekvence při použití všech kanálů je zhruba 600 Hz. Při použití menšího počtu kanálů nebo pokud není potřeba 10-bitové rozlišení lze dosáhnout vyšších frekvencí.

## 6.6 Proudová spotřeba

Logika měřící desky je napájena z USB sběrnice. To je pohodlné, jelikož k zařízení není potřeba připojovat externí zdroj napájení. Problémem je maximální povolený odběr proudu z USB sběrnice bez speciálního vyjednávání. Maximální spotřeba každého použitého integrovaného obvodu je v tabulce 6.2. Na obrázku 6.6 je znázorněna relativní spotřeba každé součásti měčící desky. V tabulce je uveden i zdroj, jak jsem se k informaci dopracoval. Pronásobení hodnoty z tabulky 6.2 počtem jednotlivých obvodů lze snadno získat maximální spotřebu celého zařízení. Vychází 285 mA. Tato hodnota je zapsána do interní EEPROM obvodu FT232R, aby došlo ke správnému uvolnění zdrojů operačním systémem. Je sice velmi nepravděpodobné, že by někdy zařízení dosáhlo takovéhoto odběru, ale standart USB vyžaduje, aby byla k dispozici informace o maximálním odběru každého zařízení.
Jelikož je spotřeba zařízení poměrně vysoká není vždy jisté, že budou k dispozici dostatečné zdroje. Při vyšším počtu připojených zařízení s větší spotřebou se může stát, že systém nebude schopen desku napájet. Tento problém operační systém ohlásí, takže není nijak složité jej odhalit. Rešením je použití hubu s vlastním napájením. ˇ

30 | 6 USB měřící deska
Obvod | Spotřeba [mA] | Zdroj informace
Atmega1280 | 25 | Spočítáno z [3, str 393 a 391]
6N134 | 26 | [6, str 6]
LM385 | 1 | Spočítáno z R13
MCP4922 | 50 | [5, str 2]
FT232R | 15 | [1, str 17]
ULN2064B | 40 | Spočítáno z [8, str 2]
ULN2803B | 4 | Spočítáno z [9, str 4]
PC849 | 1 | Spočítáno z pull-up v IC1

Tabulka 6.2: Maximální proudová spotřeba použitých součástek.


Obrázek 6.2: Podíl spotřeby jednotlivých součástek.

6.6 Proudová spotřeba | 31


Obrázek 6.3: Výsledný tištěný spoj. Cervená barva značí přední stranu desky a modrá zadní ˇ stranu desky.

32 | 7 Software

# 7 Software

## 7.1 Firmware mikroprocesoru

Firmware mikroprocesoru je napsán v jazyce C a poté přeložen pomocí svobodné sady nástrojů pro mikrokontroléry firmy Atmel, která obsahuje i kompilátor avr-gcc. Kopírování programu do FLASH paměti mikroprocesoru se děj pomocí dříve zmíněného programu Ftisp. Níže je v ”pseudo” programovacím jazyce naznačeno, jak firmware mikrokontroléru pracuje. IRQ() značí obsluhu přerušení, které probíhá paralelně s nekonečnou hlavní smyčkou programu.

While (Do nekonečna) {
Počkat dokud nejsou přijaty řídící data z PC;
Nastavit PWM výstupy podle přijatých dat;
Mastavit digitální výstupy podle přijatých dat;
Odeslat po SPI sběrnici řídící příkazy pro analogové výstupy; Přečíst stav digitálních vstupů;
Přečíst proměnnou obsahující stav analogových vstupů;
Odeslat stav analogových a digitálních vstupů do PC;
}

IRQ(AD konverze skončila) {
Uložit výsledek konverze do proměnné obsahující stav analogových vstupů; Posunout multiplexer na dalši analogový vstup;
Začít nový AD převod;
}

Ačkoliv se kód může zdát poměrně přímočarý a jednoduchý díky přitomnosti přerušení tomu tak zdaleka není. Přerušení se vyskutuje ve zdrojovém kódu firmware daleko více, ale pro názornost a jednoduchost jsou z vynechána. Díky přerušením je do běhu programu vnesena nelinearita. S tím je spojeno poměrně velké množství zádrhelů a pastí. Bližší detaily a celý zdrojový kód vyvinutého firmware je k dispozici na doprovodném CD.
Hlavní výhodou návrhu desky je možnost programovat mikroprocesor přímo v aplikaci bez nutnosti připojovat externí programátor nebo snad mikroprocesor někam vkládat. Díky této vlastnosti je šíře použití na velmi vysoké úrovni. Naprogramováním vhodného firmware je možné dosáhnout velmi nízké reakční doby měřící desky. Odezva je limitováná pouze časem, po který se vykonává jedna instrukce, což jsou řádově desítky ns. Pokud by se data posílala přes USB sběrnici do PC, tam by se provedla příslušná akce a ta by se odeslala zpět do měřící desky, tak by nebylo možné dosáhnout takto rychlé odezvy.

7.2 Rídící aplikace pro PC ˇ | 33

Vzhledem k tomu se vyvinutý firmware nijak nepokouší využívat až na designovaný limit propustnosti vstupů, rychlosti konverze A/D převodníků ani žádné další vlastnosti použíté desky. To vzhledem k univerzálnosti desky ani nejde, jelikož čas procesoru je omezený a není dost dobře možné zároveň provozovat vše libovolně rychle. Cílem je spíše ukázat, jakým způsobem se firmware programuje, které techniky a triky jsou zvykem u 8-bitových mikrokontrolérů.
Uživatel se základy programování v jazyce C, který chce desku používat k nějakému účelu může poměrně malými a rychlými modifikacemi ukázkového firmwaru dosáhnout funkčnosti, kterou požaduje.

## 7.2 Rídící aplikace pro PC ˇ

Kontrolní aplikace pro PC je napsáná ve velmi jednoduchém duchu, jak je možné zjistit z následujícího ”pseudokódu”.

While (Do nekonečna) {
Přečíst požadované stavy výstupů od užívatele; Poslat požadované stavy výstupů měřící desce. Počkat než budou přijata data z měřící desky. Zobrazit stavy vstupů z přijatých dat.
}

Vzhledem k tomu, že deska je míněna, jako co nejvíce univerzální nepokoušel jsem se napsat program, který by vyhovovala všem možným použitím desky. Takový cíl stejně není dost dobře splnitelný. Místo toho je řídící aplikace respektive její zdrojový kód spíše demonstrací, jak používat knihovnu Libftdi a jak posílat a příjímat data od měřící desky. Samotná struktura dat, zpracování a preferovaný formát ukládání jsou pro každého uživatele odlišné. Při vývoji jsem se pokoušel napsat vše tak, tak aby nebyl problém překompilovat aplikaci na co největším počtu operačních systémů. Uspěšně jsem aplikaci otestoval na Linuxu ´ (Kubuntu Janunty Jackalope), Widnows XP SP2, Windows XP SP3 a Windows Vista 32-bit. Bez úspěchu jsem byl na všech 64-bitových verzích Windows jak Vista tak XP. Problém je v nekompatibilitě Libusb. Je velmi pravděpodobné, že se v budoucnu najde někdo, kdo přeportuje Libusb i na tyto systémy. Poté bude s velmi vysokou pravděpodobností možné bez jakýchkoliv modifikací překompilovat a provozovat i řídící aplikaci.

## 7.3 Použití ve Windows

Před připojením měřící desky k počítači s OS Windows XP je vhodné nejdříve nainstalovat pořebné D2XX ovladače k obvodu FT232R. Instalace se zahájí spueštěním aplikace cd:/drivers/windows/d2x cdm 2.04.16 install.exe na doprovodném CD. Po dokončení instalace ovladačů je ještě potřeba doinstalovat Libusb-Win32. To se provede spuštěním instalačního programu libusb-win32-filter-bin-0.1.12.0.exe, který se nachází ve stejném adresáří jako ovladač D2XX.
Po nainstalovaní výše popsaného softwaru se při připojení měřící desky automaticky najdou a zavedou ovladače. Nyní je možné bez problému spustit řídící aplikaci z kontrolního CD.

34 | 7 Software

## 7.4 Použití v linuxových distribucích založených na Debianu

| Před spuštěním nebo kompilací jakékoliv řídící aplikace z CD je potřeba mít nainstalovány
knihovny libusb a libftdi. To se provede velmi jednoduše příkazem sudo apt-get install libftdi-dev libusb-dev, který ošetří všechny závislosti stáhne, nainstaluje a nakonfiguruje požadované knihovny.
| Pokud nebudeme na daném stroji kompilovat ze zdrojových kódů, tak není potřeba in-
stalovat vývojové verze knihoven a vystačíme s přikazem sudo apt-get install libftdi1 libusb-0.1-4.

## 7.5 Obsah doprovodného CD

| • cd:/applications Adresář obsahuje programy zejména pro operační systém Windows použíté k vývoji, konfiguraci a testování. Mimo jiné je obsažen program pro návrh schémat a tvorbu plošných spojů Eagle, vývojové prostředí Dev-C++, sada nástrojů pro mikrokontroléry Atmel WinAVR, program k zápisu firmware do FLASH mikroprocesoru

Ftisp, ...

| • cd:/datasheets V této složce je možné nalézt manuály ve formátu PDF k všem
použitým integrovaným obvodům.
| • cd:/drivers Zde je možné nalézt proprietární ovladače k obvodu FT232R pro různé operační sytémy. Mimo ovladače se zde ještě nachází instalátor Libusb-Win32
| • cd:/photos Tady se nacházejí fotografie pořízené při stavbě prototypů na kontaktním nepájivém poli. Odpovídající schémata se stejným názvem jsou také k dizpozici na CD.
| • cd:/schematics Ve složce jsou obsaženy zapojovací schémata vyvinutých prototypů, podklady pro výrobu plošného spoje konečné verze a mou vytvořené nebo modifikované knihovny s použitými součástkami a integrovanými obvody. Vše je navrženo programem Eagle, jehož verze, která je zdarma, je k dispozici na CD ve verzích pro Linux, Windows

a Mac OS.

| • cd:/sources V tomto adresáři se nachází vyvinuté zdrojové kódy i přeložené binární aplikace pro Windows a Linux. K dispozici jsou firmware pro mikronotrolér i řídící aplikace. Mimo kontrolní aplikace měřící desky je k dispozici i několik ukázkových

programů k demonstraci použítí Libftdi. Rídící aplikace pro Windows jsou napsány a ˇ
| přeloženy pomocí vývojového studia Dev-C++. Firmware pro mikrokontroléry je možné ve Windows upravovat a překládat pomocí sady nástrojů WinAVR. Linuxová alterna- tiva používá kvůli jednoduchosti pouze standartní Makefile v kombinaci s textovým

editorem. Všechny zdrojové kódy jsou v licenci GPL.

Literatura | 35

# Literatura

## 8.6 Použitá literatura

[1] FT232R USB UART IC Datasheet Verze 2.01, srpen 2008
cd:/datasheets/ft232r datasheet.pdf http://ftdichip.com/Documents/DataSheets/DS_FT232R.pdf
[2] UMS3 User’s Guide
Verze z 9. března 2007
cd:/datasheets/ums3 users guide.pdf http://tools.asix.net/download/usb/ums3/ums3_en.pdf
[3] ATmega640/1280/1281/2560/2561 Datasheet Revize L, srpen 2007
cd:/datasheets/atmega1280 datasheet.pdf http://atmel.com/dyn/resources/prod_documents/doc2549.pdf
[4] ATmega48/88/168 Datasheet Revize P, únor 2009
cd:/datasheets/atmega168 datasheet.pdf http://atmel.com/dyn/resources/prod_documents/doc2545.pdf
[5] MCP4921/4922 Datasheet Verze B, únor 2007
cd:/datasheets/mcp4922 datasheet.pdf http://ww1.microchip.com/downloads/en/DeviceDoc/21897B.pdf
[6] Hermetically Sealed, High Speed, High CMR, Logic Gate Optocouplers Technical Data
Verze z roku 1999
cd:/datasheets/6n134 datasheet.pdf http://www.alldatasheet.com/datasheet-pdf/pdf/104059/HP/6N134.html (http://www.alldatasheet.com/datasheet-pdf/pdf/104059/HP/6N134.html)

36 | Literatura
[7] PC829 Series Datasheet
Verze ze 17. září 2000
cd:/datasheets/pc849 datasheet.pdf http://www.ieeta.pt/~alex/docs/DataSheets/PC849.pdf
[8] 50V - 1.5A QUAD DARLINGTON SWITCHES Verze ze 9. září 2003
cd:/datasheets/uln2064b datasheet.pdf http://www.alldatasheet.com/datasheet-pdf/pdf/25568/STMICROELECTRONICS/ULN2064B.html (http://www.alldatasheet.com/datasheet-pdf/pdf/25568/STMICROELECTRONICS/ULN2064B.html)
[9] ULN2803APG 8ch Darlington Sink Driver Verze ze 15. února 2006
cd:/datasheets/uln2803a datasheet.pdf http://www.datasheetpro.com/119491_view_ULN2803A_datasheet. html (http://www.datasheetpro.com/119491_view_ULN2803A_datasheet.html)
[10] Matoušek D.: USB prakticky s obvody FTDI - 1. díl BEN - technická literatura, 1. vydání, 2003 ISBN-807300103-9
[11] Hyde J.: USB Design by Example: A Practical Guide to Building IO Devices
Intel Press, 2. vydání, 2001 ISBN-097028465-9
[12] Axelson J.: USB Complete: Everything You Need to Develop Custom USB Peripherals
Lakeview Research, 3. vydání, 2005
ISBN-193144802-7
http://books.google.com/books?id=OSnynlQrvVcC

8.7 Zdroje obrázků | 37

## 8.7 Zdroje obrázků

Obrázek 4.1: http://www.tme.eu/katalog_pics/a/e/d/ft232rl.jpg Obrázek 4.2: http://www.asix.cz/img/ums3_bot.jpg
Obrázek 4.3: [5, str 19]
Obrázek 4.4: http://www.tme.eu/katalog_pics/c/d/c/atmega1280-16au.jpg
Obrázek 4.5: http://www.coolcomponents.co.uk/catalog/images/07957-03-L.jpg Obrázek 4.6: http://media.digikey.com/photos/SharpPhotos/PC844X,844X1,845,849, 895.jpg, [7, str 1]
Obrázek 4.7: [6, str 3]
Obrázek 4.6: http://media.digikey.com/photos/SharpPhotos/PC844X,844X1,845,849, 895.jpg, [7, str 1]
Obrázek 4.8: http://media.digikey.com/photos/ToshibaPhotos/ULN2803APG(5,M).JPG, [9, str 1]
Obrázek 4.9: [8, str 1]
Obrázek 4.10: http://media.digikey.com/photos/TexasInstrPhotos/MC79L12ACLPR.JPG

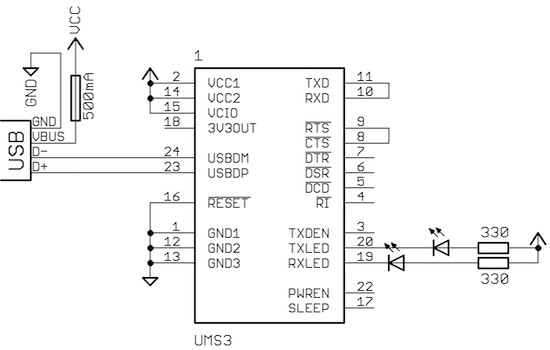
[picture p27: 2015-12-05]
prototype/discover/discover.sch.png

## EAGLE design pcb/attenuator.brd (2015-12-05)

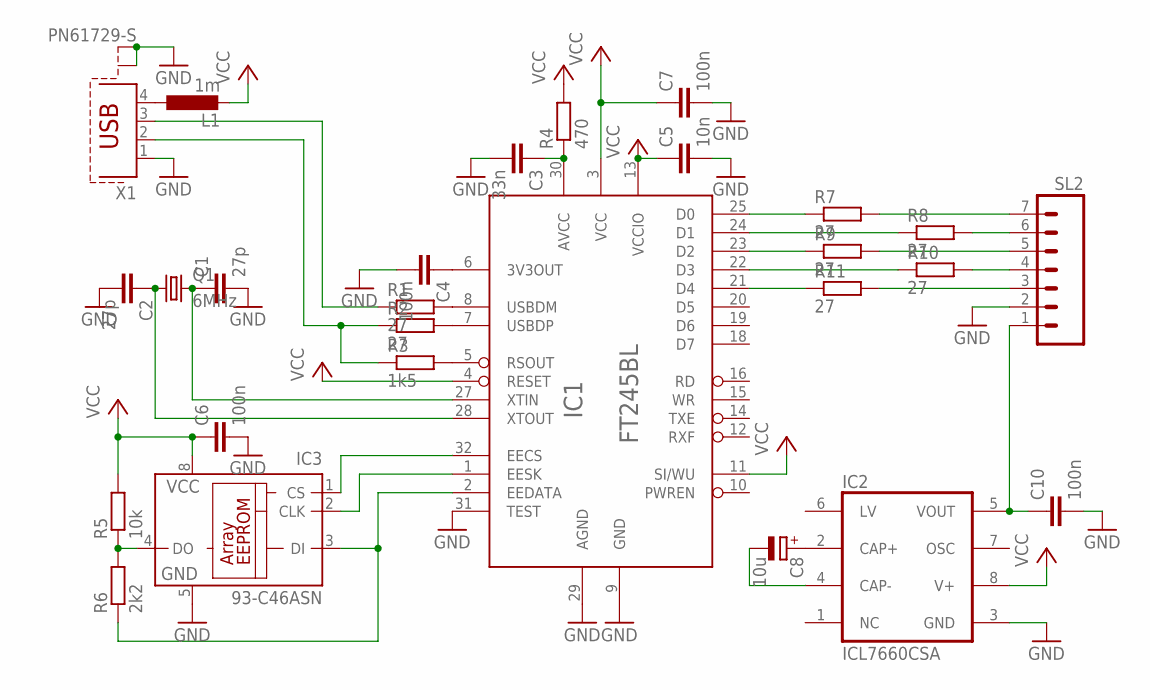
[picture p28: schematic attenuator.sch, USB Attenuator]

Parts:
C1, C2: 27p; C0805
C3: 33n; C0805
C4, C6, C7, C10: 100n; C0805
C5: 10n; C0805
C8: 10u; SMC_C
IC1: FT245BL; LQFP32
IC2: ICL7660CSA; SO08
IC3: 93-C46ASN; SO-08
L1: 1m; M0805
Q1: 6MHz; HC49U70
R1, R2, R7, R8, R9, R10, R11: 27; M0805
R3: 1k5; M0805
R4: 470; M0805
R5: 10k; M0805
R6: 2k2; M0805
SL2: MA07; 07PA
X1: PN61729-S

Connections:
GND: C1.2, C2.2, C3.2, C4.2, C5.2, C6.2, C7.2, C10.2, IC1.9 (GND), IC1.17 (GND), IC1.29 (AGND), IC1.31 (TEST), IC2.3 (GND), IC3.5 (GND), SL2.2, X1.1, X1.S1, X1.S2
unnamed: C1.1, IC1.27 (XTIN), Q1.2
unnamed: C2.1, IC1.28 (XTOUT), Q1.1
unnamed: IC1.32 (EECS), IC3.1 (CS)
unnamed: IC1.1 (EESK), IC3.2 (CLK)
unnamed: IC1.2 (EEDATA), IC3.3 (DI), R6.1
unnamed: R7.2, SL2.7
unnamed: IC3.4 (DO), R5.1, R6.2
unnamed: C8.+, IC2.2 (CAP+)
unnamed: R2.1, R3.1, X1.2
unnamed: R1.1, X1.3
unnamed: IC1.7 (USBDP), R2.2
unnamed: IC1.8 (USBDM), R1.2
unnamed: C4.1, IC1.6 (3V3OUT)
unnamed: C8.-, IC2.4 (CAP-)
unnamed: L1.1, X1.4
unnamed: R8.2, SL2.6
unnamed: R9.2, SL2.5
unnamed: IC1.22 (D3), R10.1
unnamed: IC1.21 (D4), R11.1
unnamed: IC1.25 (D0), R7.1
unnamed: IC1.24 (D1), R8.1
unnamed: IC1.23 (D2), R9.1
unnamed: R10.2, SL2.4
unnamed: R11.2, SL2.3
unnamed: C10.1, IC2.5 (VOUT), SL2.1
unnamed: C3.1, IC1.30 (AVCC), R4.1
RSOUT: IC1.5 (RSOUT), R3.2
VCC: C5.1, C6.1, C7.1, IC1.3 (VCC), IC1.4 (RESET), IC1.11 (SI/WU), IC1.13 (VCCIO), IC1.26 (VCC), IC2.8 (V+), IC3.8 (VCC), L1.2, R4.2, R5.2

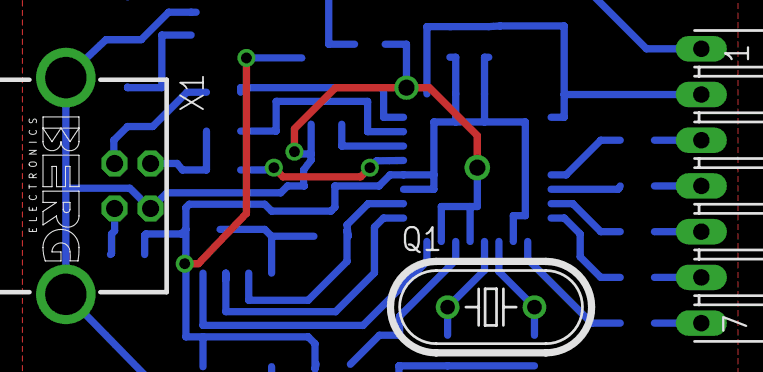
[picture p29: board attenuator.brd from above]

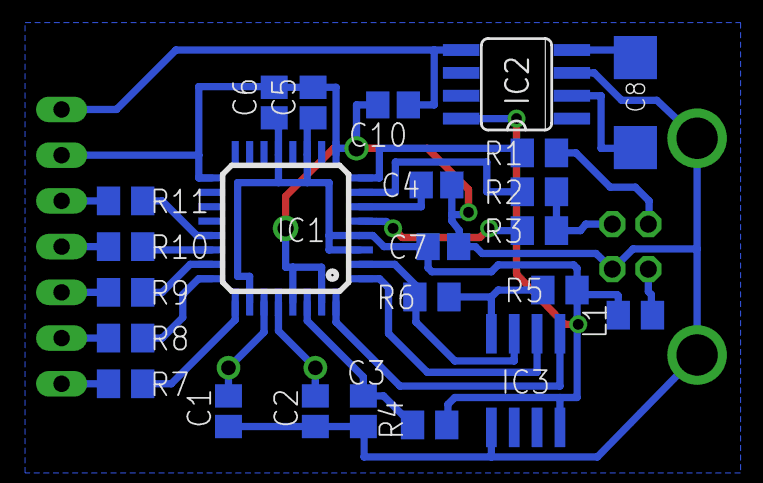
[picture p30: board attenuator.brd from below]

Board: 2 copper layers, 27 parts (24 on the bottom side), 29 nets.

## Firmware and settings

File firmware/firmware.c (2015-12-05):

/*
Firmware - USB Measuring Board Firmware for ATmega1280.

Copyright (C) 2009  Vojta Molda <vojta.molda@gmail.com>

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
You should have received a copy of the GNU General Public License
along with this program.  If not, see <http://www.gnu.org/licenses/>
*/

#include <stdio.h>
#include <stdint.h>
#include <avr/io.h>
#include <avr/interrupt.h>
#include <avr/sleep.h>

#define USBMD_FIRMWARE_SHARED
#define USBMD_FIRMWARE_PRIVATE
#include "firmware.h"


int main(void) {
	sei();
	io_init();
	dac_init();
	adc_init();
	pwm_init();
	usart_init();

	rxdata.data.dac[0] = 0;
	rxdata.data.dac[1] = 0;
	rxdata.data.dout[0] = 0;
	rxdata.data.dout[1] = 0;
	rxdata.data.pwm[0] = 0;
	rxdata.data.pwm[1] = 0;
	rxdata.data.pwm[2] = 0;
	rxdata.data.pwm[3] = 0;
	rxdata.data.pwm[4] = 0;
	rxdata.data.pwm[5] = 0;
	rxdata.data.pwm[6] = 0;
	rxdata.data.pwm[7] = 0;

	while (1) {
		// Receive data from application.
        usart_receive_data();
		// Set DAC channel #1.
		dac_set(0);
		// Set PWM duty cycle.
		pwm_set();
		// Set digital outputs.
		dout_set();
		// Get digital inputs.
		din_get();
		// Set DAC channel #2.
		dac_set(1);
		// Send data to application.
		usart_send_data();
	}
}


inline void io_init(void) {
	// Setup digital inputs and pull-up resistors.
	DDRJ = 0x00;
	PORTJ = 0xFF;
	DDRD = 0x00;
	PORTD = 0xFF;
	// Setup digital outputs.
	DDRC = 0xFF;
	DDRA = 0xFF;
}

inline void pwm_init(void) {
	// Setup PWM outputs.
	sbi(DDRB, PB6);
	sbi(DDRB, PB7);
	sbi(DDRE, PE4);
	sbi(DDRE, PE5);
	sbi(DDRH, PH4);
	sbi(DDRH, PH5);
	sbi(DDRL, PL4);
	sbi(DDRL, PL5);
	// Fast PWM mode.
	sbi(TCCR1A, WGM10);
	cbi(TCCR1A, WGM11);
	sbi(TCCR1B, WGM12);
	cbi(TCCR1B, WGM13);
	sbi(TCCR3A, WGM30);
	cbi(TCCR3A, WGM31);
	sbi(TCCR3B, WGM32);
	cbi(TCCR3B, WGM33);
	sbi(TCCR4A, WGM40);
	cbi(TCCR4A, WGM41);
	sbi(TCCR4B, WGM42);
	cbi(TCCR4B, WGM43);
	sbi(TCCR5A, WGM50);
	cbi(TCCR5A, WGM51);
	sbi(TCCR5B, WGM52);
	cbi(TCCR5B, WGM53);
	// Non-inverting PWM mode.
	sbi(TCCR1A, COM1B1);
	sbi(TCCR1A, COM1C1);
	sbi(TCCR3A, COM3B1);
	sbi(TCCR3A, COM3C1);
	sbi(TCCR4A, COM4B1);
	sbi(TCCR4A, COM4C1);
	sbi(TCCR5A, COM5B1);
	sbi(TCCR5A, COM5C1);
	// Setup clock multiplier.
	sbi(TCCR1B, CS10);
	sbi(TCCR3B, CS30);
	sbi(TCCR4B, CS40);
	sbi(TCCR5B, CS50);
}

inline void dac_init(void) {
	// Setup inputs and outptus.
	sbi(SPI_DDR, SPI_CLK);
	sbi(SPI_DDR, SPI_MOSI);
	sbi(SPI_DDR, SPI_DAC_CS);
	sbi(SPI_DDR, SPI_DAC_SHDN);
	sbi(SPI_DDR, SPI_DAC_LDAC);
	// Setup SPI master in mode 0.
	sbi(UCSR0C, UMSEL01);
	sbi(UCSR0C, UMSEL00);
	cbi(UCSR0C, UDORD0);
	cbi(UCSR0C, UCPHA0);
	cbi(UCSR0C, UCPOL0);
	// Turn on TX and RX line.
	sbi(UCSR0B, RXEN0);
	sbi(UCSR0B, TXEN0);
	// Setup SPI baudrate.
	UBRR0 = SPI_UBRR;
	// Turn on chip select.
	sbi(SPI_PORT, SPI_DAC_CS);
	// Turn on shutdown.
	sbi(SPI_PORT, SPI_DAC_SHDN);
	// Turn off latch.
	cbi(SPI_PORT, SPI_DAC_LDAC);
}

inline void adc_init(void) {
	// Turn off all other ADC pin functions.
	DIDR0 = 0xFF;
	DIDR2 = 0xFF;
	// Setup clock multiplier.
	sbi(ADCSRA, ADPS2);
	sbi(ADCSRA, ADPS1);
	sbi(ADCSRA, ADPS0);
	// Setup reference voltage.
	sbi(ADMUX, REFS0);
	// Turn on AD converter.
	sbi(ADCSRA, ADEN);
	// Turn on end of conversion IRQ.
	sbi(ADCSRA, ADIE);
	// Start conversion.
	sbi(ADCSRA, ADSC);
}

inline void usart_init(void) {
	// Setup baudrate.
	UBRR2 = USART_UBRR;
	// Turn on 2x baud rate multiplier.
	cbi(UCSR2A, U2X2);
	// Turn on TX line.
	sbi(UCSR2B, TXEN2);
	// Turn on RX line.
	sbi(UCSR2B, RXEN2);
	// Turn on byte receive IRQ.
	sbi(UCSR2B, RXCIE2);
	// Turn on empty data register IRQ.
	sbi(UCSR2B, UDRIE2);
	// Setup 8-bit transmit frame length.
	sbi(UCSR2C, UCSZ21);
	sbi(UCSR2C, UCSZ20);
	#ifdef USART_FLWCTRL
		// Setup CTS input and pull-up resistor.
		cbi(USART_DDR, USART_CTS);
		sbi(USART_PORT, USART_CTS);
		// Setup RTS output.
		sbi(USART_DDR, USART_RTS);
		sbi(USART_PORT, USART_RTS);
	#endif
}


void din_get(void) {
	txdata.data.din[0] = PIND;
	txdata.data.din[1] = PINJ;
}

void pwm_set(void) {
	OCR1B = rxdata.data.pwm[0];
	OCR1C = rxdata.data.pwm[1];
	OCR3B = rxdata.data.pwm[2];
	OCR3C = rxdata.data.pwm[3];
	OCR4B = rxdata.data.pwm[4];
	OCR4C = rxdata.data.pwm[5];
	OCR5B = rxdata.data.pwm[6];
	OCR5C = rxdata.data.pwm[7];
}

void dout_set(void) {
	PORTA = rxdata.data.dout[0];
	PORTC = rxdata.data.dout[1];
}

void dac_set(uint8_t chan) {
	while (!bv(UCSR0A, UDRE0));
	cbi(SPI_PORT, SPI_DAC_CS);
	switch (chan) {
		case 0:
			UDR0 = ((rxdata.data.dac[0] >> 8) | DAC0_MASK);
			break;
		case 1:
			UDR0 = ((rxdata.data.dac[1] >> 8) | DAC1_MASK);
			break;
	}
	UDR0 = rxdata.data.dac[chan];
	sbi(UCSR0B, TXCIE0);
}


void usart_send_data(void) {
	uint8_t tx_size = 0;
	while (tx_size < sizeof(txdata_t)) {
		usart_putchar(txdata.raw[tx_size]);
		tx_size++;
	}
}

void usart_putchar(char byte) {
	while (tx.size == TXBUF_SIZE);
	tx.wr++;
	tx.size++;
	tx.wr &= TXBUF_MASK;
	tx.buf[tx.wr] = byte;
	sbi(UCSR2B, UDRIE2);
	return;
}

char usart_getchar(void) {
	while (rx.size == 0);
	rx.rd++;
	rx.size--;
	rx.rd &= RXBUF_MASK;
	#ifdef USART_FLWCTRL
		if (rx.size < (RXBUF_SIZE - RXBUF_MARGIN)) {
			sbi(USART_PORT, USART_RTS);
		}
	#endif
	return rx.buf[rx.rd];
}

void usart_receive_data(void) {
	uint8_t rx_size = 0;
	while (rx_size < sizeof(rxdata_t)) {
		rxdata.raw[rx_size] = usart_getchar();
		rx_size++;
	}
}


ISR(USART2_UDRE_vect, ISR_BLOCK) {
	if (tx.size == 0) {
		cbi(UCSR2B, UDRIE2);
	} else {
		#ifdef USART_FLWCTRL
			while (!bv(USART_PIN, USART_CTS));
		#endif
		tx.rd++;
		tx.size--;
		tx.rd &= TXBUF_MASK;
		UDR2 = tx.buf[tx.rd];
	}
}

ISR(USART2_RX_vect, ISR_BLOCK) {
	rx.wr++;
	rx.size++;
	rx.wr &= RXBUF_MASK;
	rx.buf[rx.wr] = UDR2;
	#ifdef USART_FLWCTRL
		if (rx.size > (RXBUF_SIZE - RXBUF_MARGIN)) {
			cbi(USART_PORT, USART_RTS);
		}
	#endif
}

ISR(ADC_vect, ISR_BLOCK) {
	static uchar mux = 0;
	txdata.data.adc[mux] = ADC;
	switch (mux) {
		case (ADCBUF_SIZE - 1):
			cbi(ADCSRB, MUX5);
			mux = 0;
			break;
		case 7:
			sbi(ADCSRB, MUX5);
			mux++;
			break;
		default:
			mux++;
	}
	ADMUX = (ADMUX & ADCBUF_MASK) | (mux & ADCMUX_MASK);
	sbi(ADCSRA, ADSC);
}

ISR(USART0_TX_vect, ISR_BLOCK) {
	sbi(SPI_PORT, SPI_DAC_CS);
	cbi(UCSR0B, TXCIE0);
}

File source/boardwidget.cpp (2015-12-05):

/*
QBoardWidget - Controller widget that manages USB Measuring Board
PCB based on FT232 and ATmega1280 ICs.

Copyright (C) 2009  Vojta Molda <vojta.molda@gmail.com>

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
You should have received a copy of the GNU General Public License
along with this program.  If not, see <http://www.gnu.org/licenses/>
*/

#include "boardwidget.h"

QBoardWidget::QBoardWidget(QWidget *parent) :
    QWidget(parent), board(NULL)
{
    setupUi(this);
    aoSetup();
    doSetup();
    pwmSetup();

    timer = new QTimer(this);
    QObject::connect(timer, SIGNAL(timeout()),
                     this, SLOT(transmit()));
}

void QBoardWidget::connect() {
    if (board != NULL) {
        QObject::connect(this->board, SIGNAL(deviceConnected(bool)),
                         this, SLOT(deviceConnected(bool)));
        QObject::connect(this->board, SIGNAL(deviceFailed(int)),
                         this, SLOT(deviceFailed(int)));
        memset(&(txdata.raw), 0, sizeof(txdata_t));
        memset(&(rxdata.raw), 0, sizeof(rxdata_t));
        board->connect(USART_BAUD, 1, sizeof(rxdata_t), sizeof(txdata_t));
    } else {
        emit boardConnected(false);
    }
    timer->start();
}

void QBoardWidget::transmit() {
    aoSync();
    doSync();
    pwmSync();
    if (board != NULL) {
        board->transmit((uchar*)&(rxdata.raw), sizeof(rxdata_t));
        board->receive((uchar*)&(txdata.raw), sizeof(txdata_t));
    }
    aiSync();
    diSync();
}

void QBoardWidget::disconnect() {
    timer->stop();
    if (board != NULL) {
        board->disconnect();
    } else {
        emit boardConnected(false);
    }
}

void QBoardWidget::deviceConnected(bool flag) {
    setEnabled(flag);
    emit boardConnected(flag);
}

void QBoardWidget::deviceFailed(int error) {
    QMessageBox messageBox;
    messageBox.setIcon(QMessageBox::Critical);
    messageBox.setInformativeText(tr("Please verify that the device is properly connected."));
    if (board != NULL) messageBox.setDetailedText(board->getErrorMessage());
    if (error == QFtdiDevice::Error.InitFailed) {
        messageBox.setText(tr("Initialization failed."));
    } else if (error == QFtdiDevice::Error.ConnectFailed) {
        messageBox.setText(tr("Connection failed."));
    } else if (error == QFtdiDevice::Error.TransmitFailed) {
        messageBox.setText(tr("Data transmission failed."));
    } else if (error == QFtdiDevice::Error.ReceiveFailed) {
        messageBox.setText(tr("Data receiving failed."));
    } else if (error == QFtdiDevice::Error.DisconnectFailed) {
        messageBox.setText(tr("Disconnect failed."));
    } else {
        return;
    }
    messageBox.exec();
    emit boardFailed(error);
    disconnect();
}

void QBoardWidget::storeSettings(QSettings &settings) const {
    settings.setValue(SettingKey.ReferenceVoltage(), getReferenceVoltage());
    if ((board != NULL) && (board->isConnected())) {
        settings.setValue(SettingKey.Board(), true);
        settings.beginGroup(SettingKey.Board());
        board->storeSettings(settings);
        settings.endGroup();
    } else {
        settings.remove(SettingKey.Board());
    }
}

void QBoardWidget::restoreSettings(QSettings &settings) {
    double referenceVoltage = settings.value(SettingKey.ReferenceVoltage(), Default.ReferenceVoltage()).toDouble();
    setReferenceVoltage(referenceVoltage);
    if (settings.childGroups().contains(SettingKey.Board())) {
        settings.beginGroup(SettingKey.Board());
        setBoard(new QFtdiDevice(settings, this));
        settings.endGroup();
        connect();
    } else {
        setBoard(NULL);
    }
}

void QBoardWidget::setBoard(QFtdiDevice *board) {
    if (this->board != NULL) {
        disconnect();
        delete this->board;
    }
    this->board = board;
    if (this->board != NULL) {
        this->board->setParent(this);
    }
}

QFtdiDevice* QBoardWidget::getBoard() const {
    return board;
}

void QBoardWidget::setReferenceVoltage(const double referenceVoltage) {
    this->referenceVoltage = referenceVoltage;
    aoSpinBox_0->setMaximum(referenceVoltage);
    aoSpinBox_1->setMaximum(referenceVoltage);
}

double QBoardWidget::getReferenceVoltage() const {
    return referenceVoltage;
}

void QBoardWidget::changeEvent(QEvent *event) {
    QWidget::changeEvent(event);
    if (event->type() == QEvent::LanguageChange) {
        retranslateUi(this);
    }
}
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

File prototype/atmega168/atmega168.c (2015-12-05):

/*
ATmega168 - Breadboard Prototype Application.

Copyright (C) 2009  Vojta Molda <vojta.molda@gmail.com>

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
You should have received a copy of the GNU General Public License
along with this program.  If not, see <http://www.gnu.org/licenses/>
*/

#include <ftdi.h>
#include <stdio.h>
#include <stdint.h>
#include <signal.h>
#include <stdlib.h>
#ifdef _WIN32
	#include <windows.h>
#else
	#include <unistd.h>
#endif

#define ATMEGA168_FIRMWARE_SHARED
#include "firmware/atmega168.h"


void delay(unsigned int msec);
void terminate(int retval);


struct ftdi_context ftdic;


int main(int argc, char **argv) {
	rxdata_t rxdata;
	txdata_t txdata;

	signal(SIGINT, terminate);

	if (ftdi_init(&ftdic) < 0) {
		fprintf(stderr, "FTDI init failed - %s.\n", ftdi_get_error_string(&ftdic));
		return 1;
	}
	if (ftdi_usb_open(&ftdic, 0x0403, 0x6001) < 0) {
		fprintf(stderr, "USB open failed - %s.\n", ftdi_get_error_string(&ftdic));
		return 2;
	}
 	if (ftdi_set_baudrate(&ftdic, USART_BAUD) < 0) {
 		fprintf(stderr, "Set baud rate failed - %s.\n", ftdi_get_error_string(&ftdic));
 		return 3;
 	}
	if (ftdi_set_line_property(&ftdic, BITS_8, STOP_BIT_1, NONE) < 0) {
		fprintf(stderr, "Set line property failed- %s.\n", ftdi_get_error_string(&ftdic));
		return 4;
	}

	while (1) {

		rxdata.data.dout[0] = 255;
		rxdata.data.dout[1] = 255;

		rxdata.data.dac[0] = 4095;
		rxdata.data.dac[1] = 2048;

		rxdata.data.pwm[0] = 128;
		rxdata.data.pwm[1] = 128;
		rxdata.data.pwm[2] = 0;
		rxdata.data.pwm[3] = 0;
		rxdata.data.pwm[4] = 128;
		rxdata.data.pwm[5] = 128;
		rxdata.data.pwm[6] = 128;
		rxdata.data.pwm[7] = 128;

		if (ftdi_write_data(&ftdic, (unsigned char*) rxdata.raw, sizeof(rdata_t)) < 0) {
			fprintf(stderr, "Read data failed - %s\n", ftdi_get_error_string(&ftdic));
			return 5;
		}

		delay(100);

		if (ftdi_read_data(&ftdic, (unsigned char*) txdata.raw, sizeof(tdata_t)) < 0) {
			fprintf(stderr, "Read data failed - %s\n", ftdi_get_error_string(&ftdic));
			return 6;
		} else {
			printf("Analog inputs: %4d %4d %4d %4d %4d %4d.\n",
					txdata.data.adc[0], txdata.data.adc[1], txdata.data.adc[2],
					txdata.data.adc[3], txdata.data.adc[4], txdata.data.adc[5]);
			printf("Digital inputs: %3d %3d.\n", txdata.data.din[0], txdata.data.din[1]);
		}
	}

	terminate(0);
}


void delay(unsigned int msec) {
	#ifdef _WIN32
		Sleep(msec);
	#else
		usleep(msec*1000);
	#endif
}


void terminate(int retval) {
	printf("\nTerminating...\n");
	if (ftdi_usb_close(&ftdic) < 0) {
		fprintf(stderr, "USB close failed - %s.\n", ftdi_get_error_string(&ftdic));
		retval = 7;
	}
	ftdi_deinit(&ftdic);
	exit(retval);
}

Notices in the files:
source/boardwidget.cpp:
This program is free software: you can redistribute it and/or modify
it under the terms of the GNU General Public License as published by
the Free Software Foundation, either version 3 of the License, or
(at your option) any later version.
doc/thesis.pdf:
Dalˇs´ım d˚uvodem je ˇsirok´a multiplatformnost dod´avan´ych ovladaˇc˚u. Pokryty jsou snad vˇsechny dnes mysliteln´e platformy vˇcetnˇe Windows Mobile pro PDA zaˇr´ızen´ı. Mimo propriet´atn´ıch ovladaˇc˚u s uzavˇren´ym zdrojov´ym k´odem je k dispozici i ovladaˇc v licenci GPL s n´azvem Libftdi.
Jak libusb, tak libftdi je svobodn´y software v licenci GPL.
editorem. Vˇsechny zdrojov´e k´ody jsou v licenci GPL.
